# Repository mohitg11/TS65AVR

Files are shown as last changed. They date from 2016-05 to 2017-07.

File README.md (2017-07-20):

# TS65 - AVR Based
The Split 65% Keyboard - AVR Based

This is a custom 65% style keyboard that is split in the middle to provide a more ergonomic option whilst not being drastically different from the standard stagger used on keyboards

#Features
- Open Source Design
- Fully Programmable Keys
- Split design for better ergonomics, while maintaining the currently "standard" keyboard layput
- PCBs and case designed so that the two sides can be aligned perfectly like a 65%, for others using the board, cleaner desk while not at it, etc.
- Multiple layers
- Alps/Cherry (PCB/Plate) switch support
- PCB mount stabs supported
- Backlight LED on top to maintain compatibility with the few backlit keysets out there
- 3 Indicator + CapsLock LED
- 18 SMD RGB LEDs on the bottom of the PCB for under/side glow
- SMD (SOD-123) diodes
- Individual resistors for the LEDs not required as it uses a dedicated LED driver
- Using large (0805) capacitors and resistors so it is easier to hand-solder

#Optional Features Supported
- Possibility to add a buzzer
- Possibility to add a PS/2 trackpoint to either halves.
- Possibility to add a rotary dial for changing volume, LED brightness, etc.

#Layout options
- Split backspace
- Split left shift
- ISO support
- Off-center capslock
- 2.75 and 1.75 right shift
- Lots of options for bottom row

In the below image you can see the different options available, the top four rows represent the four rows of th keyboard and the options for the final keyboard row is represented by the remaining rows in the image.
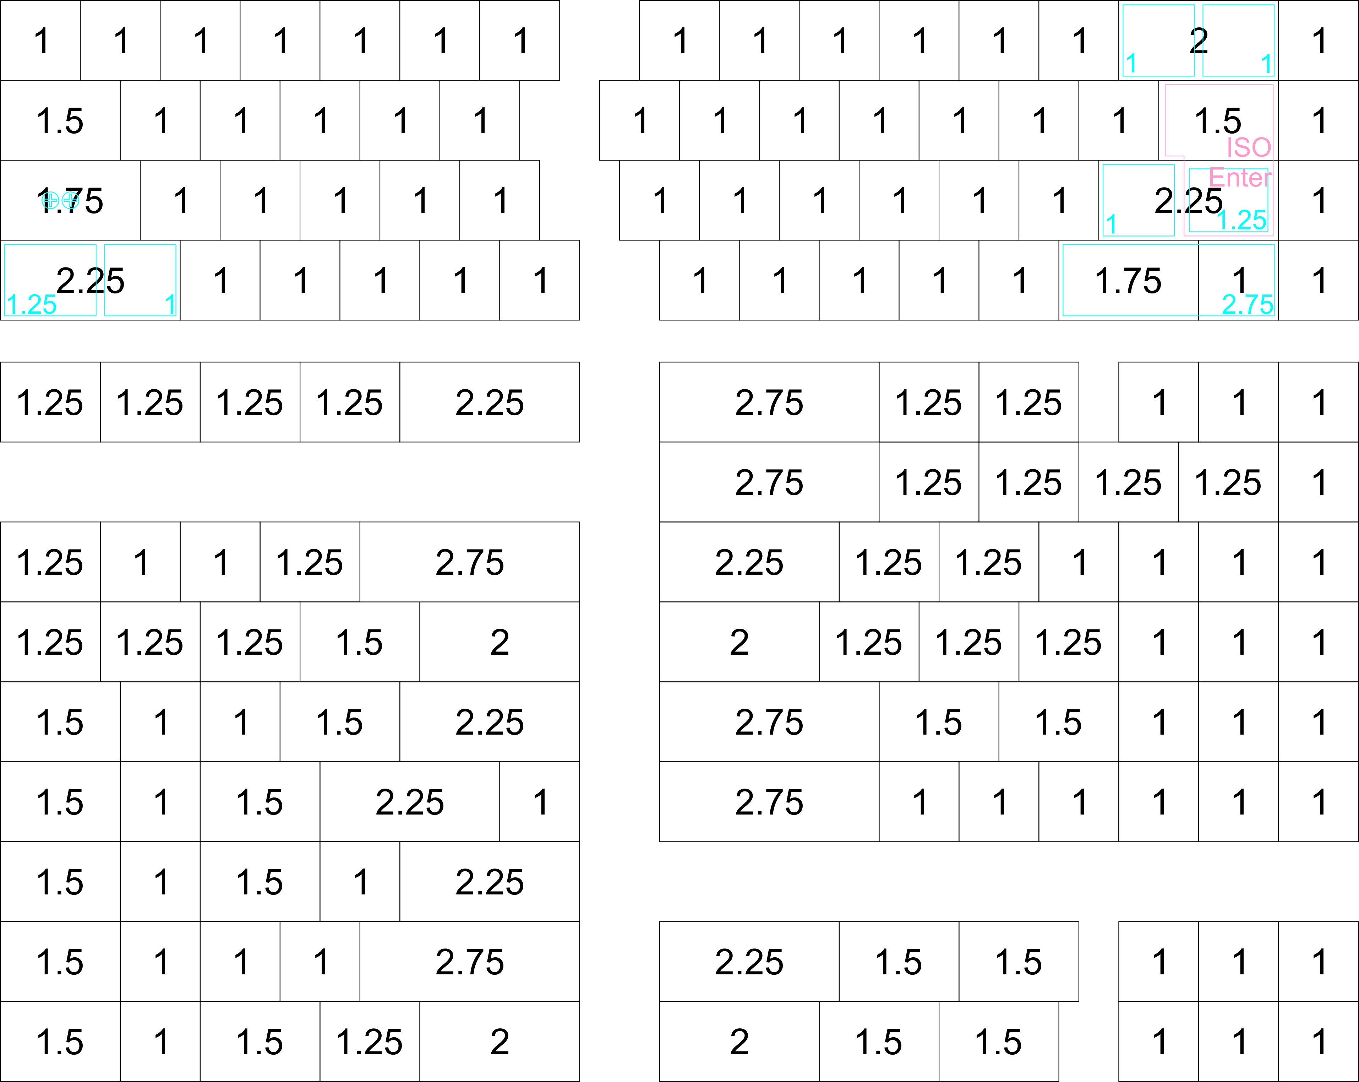
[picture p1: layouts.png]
Layout Options


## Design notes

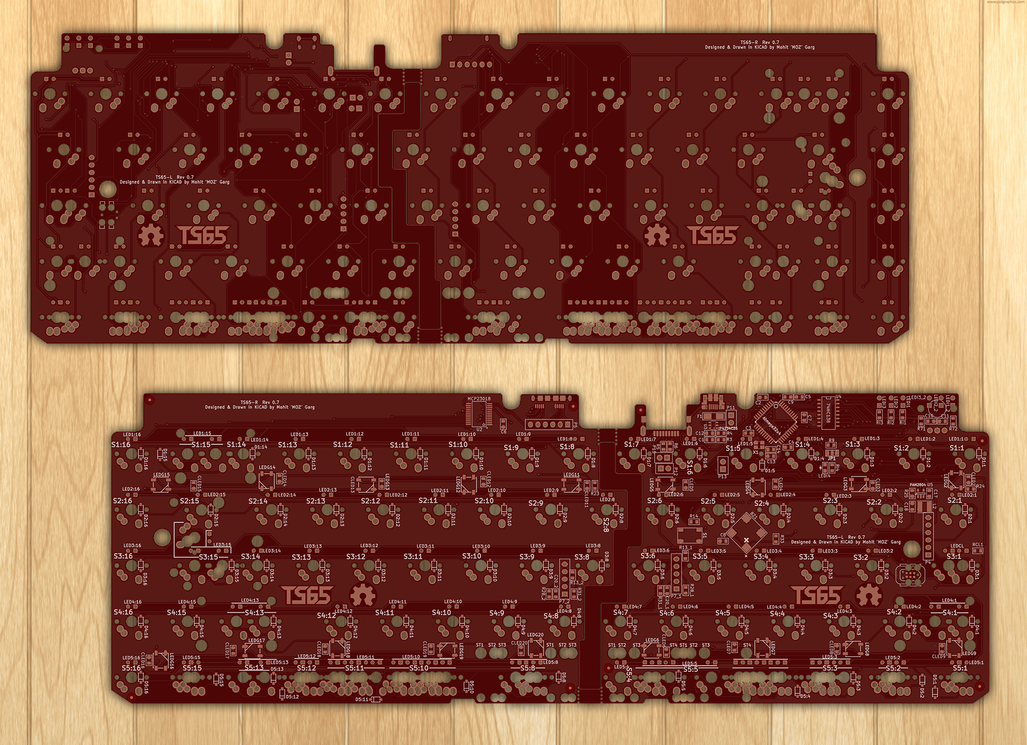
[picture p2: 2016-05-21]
PCB.png

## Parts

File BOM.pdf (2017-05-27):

# | Reference | Value | Qty | Description | Product | Vendor

1 | C1, C2 | 1uF | 2 | CAP CER 1UF 10V 10% X7R 0805 | CC0805KKX7R6BB105 | Yageo
2 | C12, C17, C18 | 10uF | 3 | CAP CER 10UF 6.3V X5R 0805 | CC0805KKX5R5BB106 | Yageo
3 | C13, C14 | 8pF | 2 | CAP CER 8PF 50V NP0 0805 | CC0805DRNPO9BN8R0 | Yageo
4 | CLED1 ‐ CLED20, C3‐C7, C9 | 0.1 uF | 24 | CAP CER 0.1UF 16V X7R 0805 | CL21B104KOANNNC | Yageo
5 | D1:1 ‐ D5:16 | DIODE | 73 | 1N4148 SOD123 DIODE | 1N4148W‐FDICT‐ND | Diodes Inc
6 | F1 | PTC FUSE | 1 | PTC RESTTBLE 1.0A 6V CHIP 1206 | 0ZCJ0100FF2E | Bel Fuse Inc
7 | L2 | 4.7uH | 1 | FIXED IND 4.7UH 1.9A 84 MOHM SMD | SRN4018‐4R7M | Bourns Inc
8 | LED1:1 | LED | 76 | 2x3x4mm 1.8mm 3mm flangeless LED
9 | LEDG2 - LEDG9, LEDG11 - LEDG20 WS2812B | 18 | LED RGB WS2812B W/DVR 4SMD 10PK | WS2812B | WorldSemi
10 | LEDI4 | LED | 1 | 0805 SMD LED
11 | P1 | USB_CONN | 1 | USB Micro B Female | 10103594‐0001LF | Amphenol
12 | P2 | USB3 | 1 | USB 3.0 A Female | AU-Y1006-3 | Assmann WSW Components
13 | P3 | USB3_MICRO | 1 | USB 3.0 Micro B Female | GSB343K33HR | Amphenol
14 | R23. R24 | 330 | 2 | RES SMD 330 OHM 1% 1/8W 0805 | RC0805FR‐07330RL | Yageo
15 | R25 | RLED | 1 | Resistor to set LED current select 0.1/I | RL0805FR‐7W0R5L | Yageo
16 | R3, R4 | 22 | 2 | RES SMD 22 OHM 5% 1/8W 0805 | RC0805FR‐0722RL | Yageo
17 | R9 | 10k | 1 | RES SMD 10K OHM 1% 1/8W 0805 | RC0805FR‐0710KL | Yageo
18 | R5, R6 | 2.2k | 2 | RES SMD 2.2K OHM 1% 1/8W 0805 | RC0805FR‐072K2L | Yageo
19 | R14 | 100k | 2 | RES SMD 100K OHM 1% 1/8W 0805 | RC0805FR‐07100KL | Yageo
20 | RCL1, RI1‐RI4 | 470 | 5 | 0805 Resistor for LED | RC0805FR‐07470KL | Yageo
21 | S1 | TAC_SWITCH | 1 | SWITCH TACTILE SPST‐NO 0.02A 15V | PTS525SM15SMTR2 LFS | C&K Components
22 | S1:1 ‐ S5:16 | SW | 73 | MX Alps or compatible switch
23 | U1 | Atmega32u4 | 1 | IC MCU 8BIT 32KB FLASH 44TQFP | ATMEGA32U4‐AU | Atmel
24 | U2 | MCP23018 | 1 | IC I/O EXPANDER I2C 16B 24SSOP | MCP23018‐E/SS | Microchip
25 | U3 | IP4234CZ6 | 1 | TVS DIODE 5.5VWM 6TSOP | IP4234CZ6 | NXP
26 | U4 | 74HC138 | 1 | IC DECODER/DEMUX 3‐8 LINE 16SOIC | 74HC138D | NXP
27 | U5 | PAM2804 | 1 | LED Driver IC 1 Output DC DC Buck 1A | PAM2804AAB010 | Diodes Inc
28 | X1 | CRYSTAL | 1 | Crystal 16.0000MHz 15ppm 8pF 50 Ohm | NX3225SA‐16.000MHZ‐STD‐CSR‐1 | NDK
# | Buzzer (Optional)

1 | BZ1 | BUZZER | 1 | BUZZER MAGNETIC 3.6V 8.5MM SMD | SMT‐0931‐S‐R | PUI Audio Inc
2 | C8 | 0.1uF | 1 | CAP CER 0.1UF 16V X7R 0805 | CL21B104KOANNNC | Yageo
3 | R33 | 100 | 1 | RES SMD 100 OHM 1% 1/8W 0805 | RC0805FR‐07100RL | Yageo
# | Trackpoint (Optional)

1 | C20 | 2.2uF | 1 | CAP CER 2.2UF 10V X7R 0805 | CC0805KKX7R6BB225 | Yageo
2 | R13 | 100k | 1 | RES SMD 100K OHM 1% 1/8W 0805 | RC0805FR‐07100KL | Yageo
3 | R28, R31 | 4.7k | 2 | RES SMD 4.7K OHM 1% 1/8W 0805 | RC0805FR‐074K7L | Yageo
# | Rotary Encoder (Optional)

1 | C10, C11 | 1uF | 2 | CAP CER 1UF 10V 10% X7R 0805 | CC0805KKX7R6BB105 | Yageo
2 | R71, R72 | 10k | 2 | RES SMD 10K OHM 1% 1/8W 0805 | RC0805FR‐0710KL | Yageo
3 | S2 | ENCODER | 1 | ENCODER ROTARY | PEC12R‐4017F‐N0024 | Bourns Inc

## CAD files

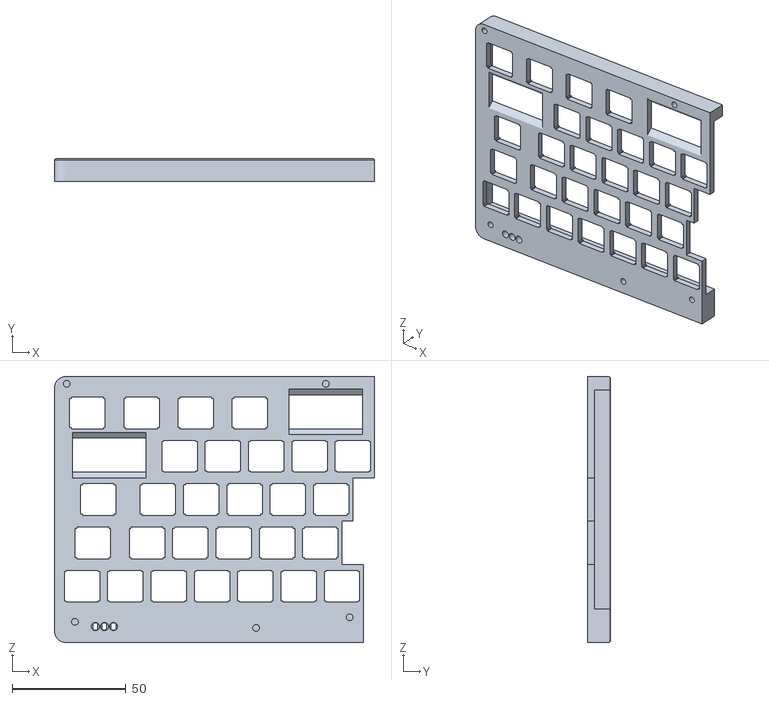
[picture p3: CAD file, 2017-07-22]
Case/3d Printed/Plate-Left.stl
140.7 x 10.0 x 117.0

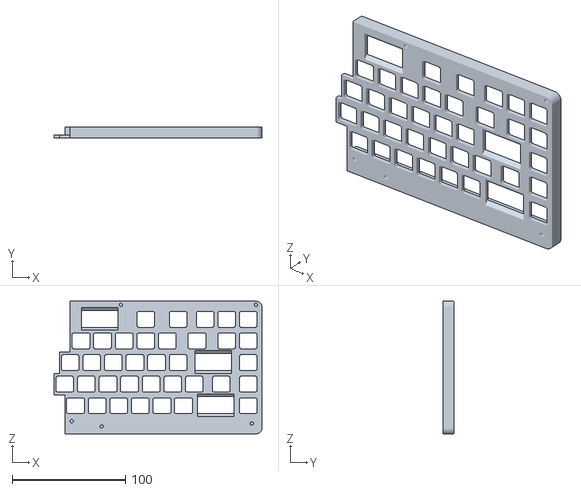
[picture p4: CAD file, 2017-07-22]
Case/3d Printed/Plate-Right.stl
183.6 x 10.0 x 117.0

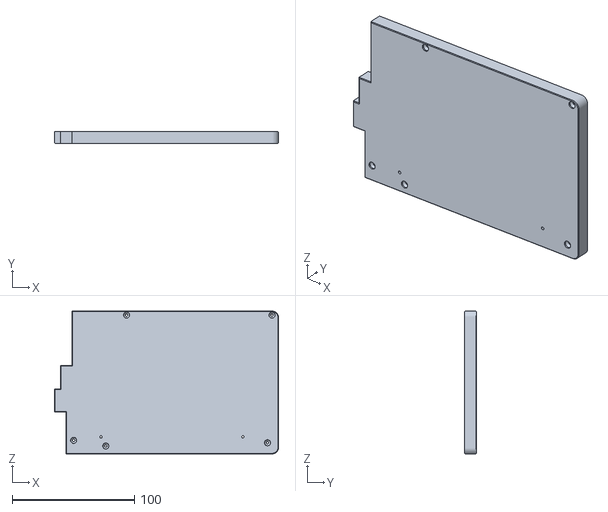
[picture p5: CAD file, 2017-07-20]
Case/3d Printed/Bottom-Right.stl
183.6 x 10.0 x 117.0

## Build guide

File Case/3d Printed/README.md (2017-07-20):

# 3d printed case

A 3d printed case for the TS65 keyboard by GH/MajorKoos.  
This model is designed for printing on a FDM printer without the need for supports.

#McMaster-Carr parts #:
- 94180A307    Heat-Set Inserts for Plastics M2 x 0.4 mm Thread Size, 2.9 mm 
- 91294A009    Black-Oxide Alloy Steel Hex Drive Flat Head Screw M2 x 0.4 mm Thread, 12 mm Long

#Reference
https://geekhack.org/index.php?topic=79161.msg2462175#msg2462175

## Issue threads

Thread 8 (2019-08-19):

ISO Layout for Plate files

sachin3767, 2019-08-19:
Hi, I've been following the TS65 on GH which led me here. I hope this git is still being updated.

Would it be possible to have an ISO layout for the plate files? Mostly to provide others with some options on layouts. I much prefer the fixed layout as you have for ANSI, but separate files for other layouts would be handy.

[KLE example layout](http://www.keyboard-layout-editor.com/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"%0A'&=%60%0A~&_x:1.25&c=%235b6e7f&a:7%3B&=PGUP%3B&@_w:1.25%3B&=SHIFT&_c=%23dcd9d4&a:5%3B&=%5C%0A%7C&_a:7%3B&=Z&=X&=C&=V&=B&_x:0.75%3B&=N&=M&=,&=.&=%2F%2F&_c=%235b6e7f&w:1.75%3B&=SHIFT&_c=%23ffb734%3B&=UP&_c=%235b6e7f%3B&=PGDN%3B&@_w:1.25%3B&=CTRL&_w:1.25%3B&=WIN&_c=%23ffb734&w:1.25%3B&=FN&_c=%235b6e7f&w:1.25%3B&=ALT&_c=%23ffb734&w:2.25%3B&=&_x:0.75&c=%235b6e7f&w:2.75%3B&=&=ALT&_c=%23ffb734%3B&=FN&_c=%235b6e7f%3B&=CTRL&_c=%23ffb734%3B&=LEFT&=DN&=RIGHT)

Thank you

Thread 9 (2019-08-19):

BOM does not include trackpoint product code

sachin3767, 2019-08-19:
As the title suggests, I cannot see a trackpoint product code. Where would I find a compatible trackpoint for this PCB?

coddingtonbear, 2019-12-01:
It's unlikely you're going to be able to find a useful product code for such a thing.   Essentially -- you just need to find a trackpoint with PS/2 support; you can find a brief overview of some known-compatible trackpoints here: https://deskthority.net/wiki/TrackPoint_Hardware.  What _I_ did in my design was harvest a trackpoint from a Lenovo R61 keyboard.

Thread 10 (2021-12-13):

0805 Resistor for LED is 470 or 470k?

NewTX, 2021-12-13:
Hi, I don't know much about hardware, so this makes me confuse.
In BOM-TS65.xlsx, No20 is 0805 resistor for LED. It's value is 470, but the product code "RC0805FR‐07470KL" is for 470k.
So, which one should I use?'

Thank you.

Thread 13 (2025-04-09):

Suspected Fake Star Pumping and Dishonest Behavior 🚨

steinmetz-phillipi, 2025-04-09:
Hey there 👋,

First off, love seeing creative projects on GitHub, but I stumbled upon something strange here. It seems like your repo's GitHub stars grew suspiciously fast—like unrealistically fast, to the point it looks like someone might have paid for fake stars or used some shady star-boosting methods.

Why's this a problem? Well, GitHub is all about genuine collaboration and sharing cool stuff, right? Buying fake stars or artificially inflating popularity hurts trust in the community and makes it unfair for other hardworking developers.

Mistakes happen, so if this was intentional or accidental, it’d be cool to own up to it and fix the situation. Authentic growth is far better long-term—you win genuine respect rather than superficial attention.

Maybe consider taking some steps to reset fake data/influences here? And trust me, if your project has value (it totally seems to), it’ll get deserved recognition organically.

Keeping GitHub awesome for everyone starts with each of us!✌️

coddingtonbear, 2025-04-09:
@mohitg11  --  I think any of us following this repo know that this claim is absolutely absurd given the star count of this repo.  Please don't feel weird just closing these unceremoniously.

Closed 2025-04-09.

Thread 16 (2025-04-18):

Unusual Spike in GitHub Stars - Questionable Practices?

cburton6338-o, 2025-04-18:
Hi there, I know open-source contributions and community recognition can be exciting, but I couldn’t help but notice an unusually sharp rise in the number of this project’s stars recently. It feels a bit off, almost like there’s some "help" involved, maybe star-buying? 😅

If this was intentional (or a misunderstanding gone funny), I’d strongly encourage reflecting on the real purpose of open source. Manipulating metrics just dilutes trust in the community. It's way cooler to have fewer but genuine supporters than inflated vanity numbers. Quality over quantity!

So, how about doing the right thing—owning up, clarifying or reversing any unintended actions DIY style? 😄 Transparency rocks, and the open-source world can show enough support naturally if you're passionate and persistent.

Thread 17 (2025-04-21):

关于项目的异常 Star 增长的疑问

ciara5054-hey2, 2025-04-21:
嗨，作者！最近注意到这个项目的 GitHub Star 数量在短时间内出现了异常的增长，看上去不像是自然获得的社区支持呢。这样的“刷 Star”行为，真的对开源项目的发展好吗？

开源社区重视的是透明、真实的贡献和价值，而不是表面的人气数字。如果这些 Star 是通过购买或者类似的方式获得的，我建议你重视这个问题，承认错误，并公开道歉。

虚假的人气可能一时看起来风光，但从长远来看，对项目的信任和声誉伤害更大。开源是关于真诚和共同进步的，希望你也能够以实际行动为社区树立一个正面的榜样！加油，我们都在期待一个更真实、更有价值的项目成长！

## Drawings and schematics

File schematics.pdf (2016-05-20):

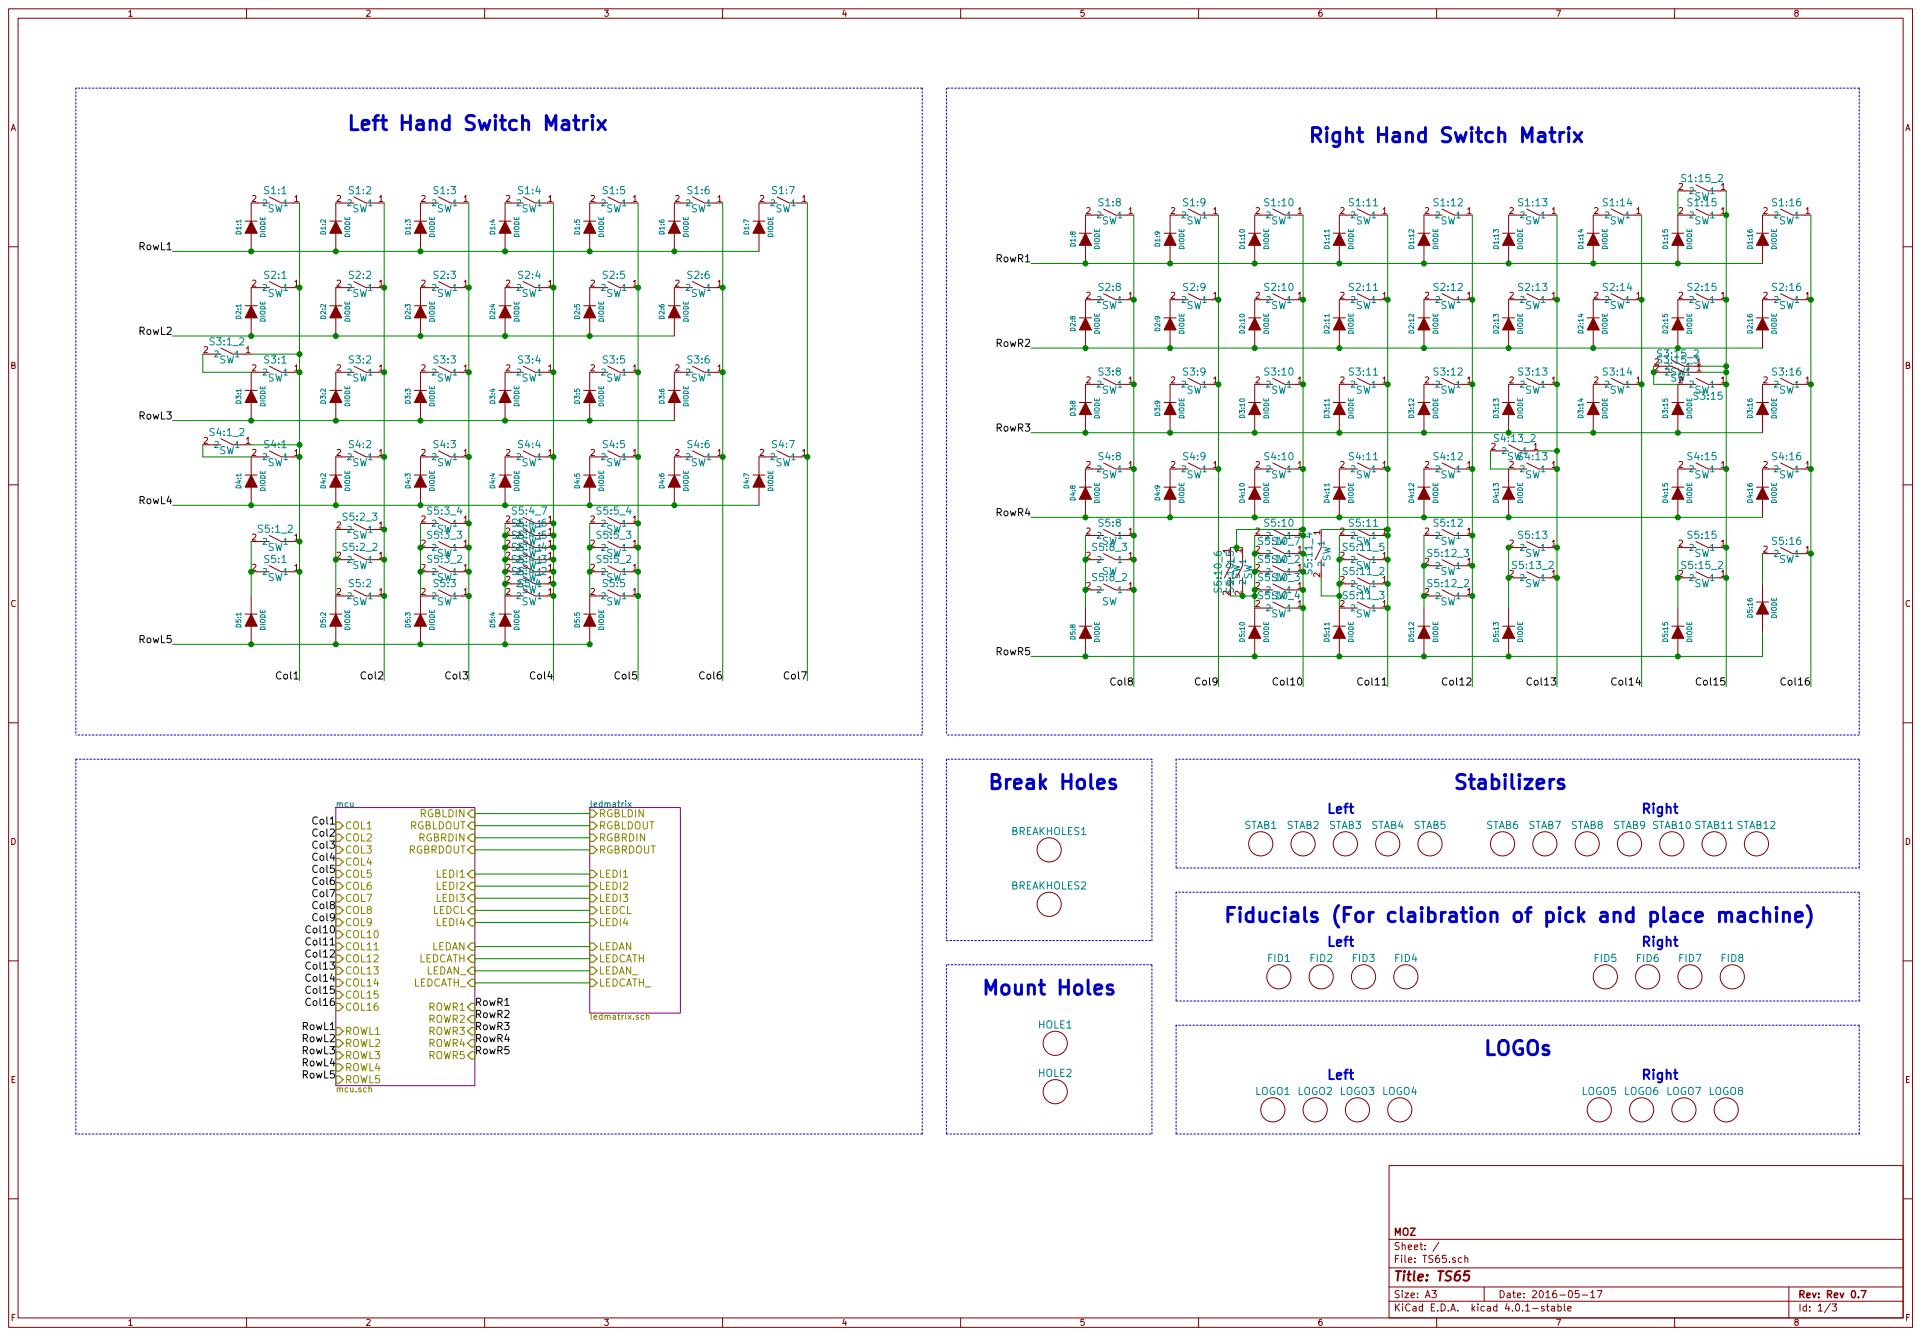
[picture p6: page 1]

File: TS65.sch Sheet: / MOZ BREAKHOLES2

Fiducials (For claibration of pick and place machine)

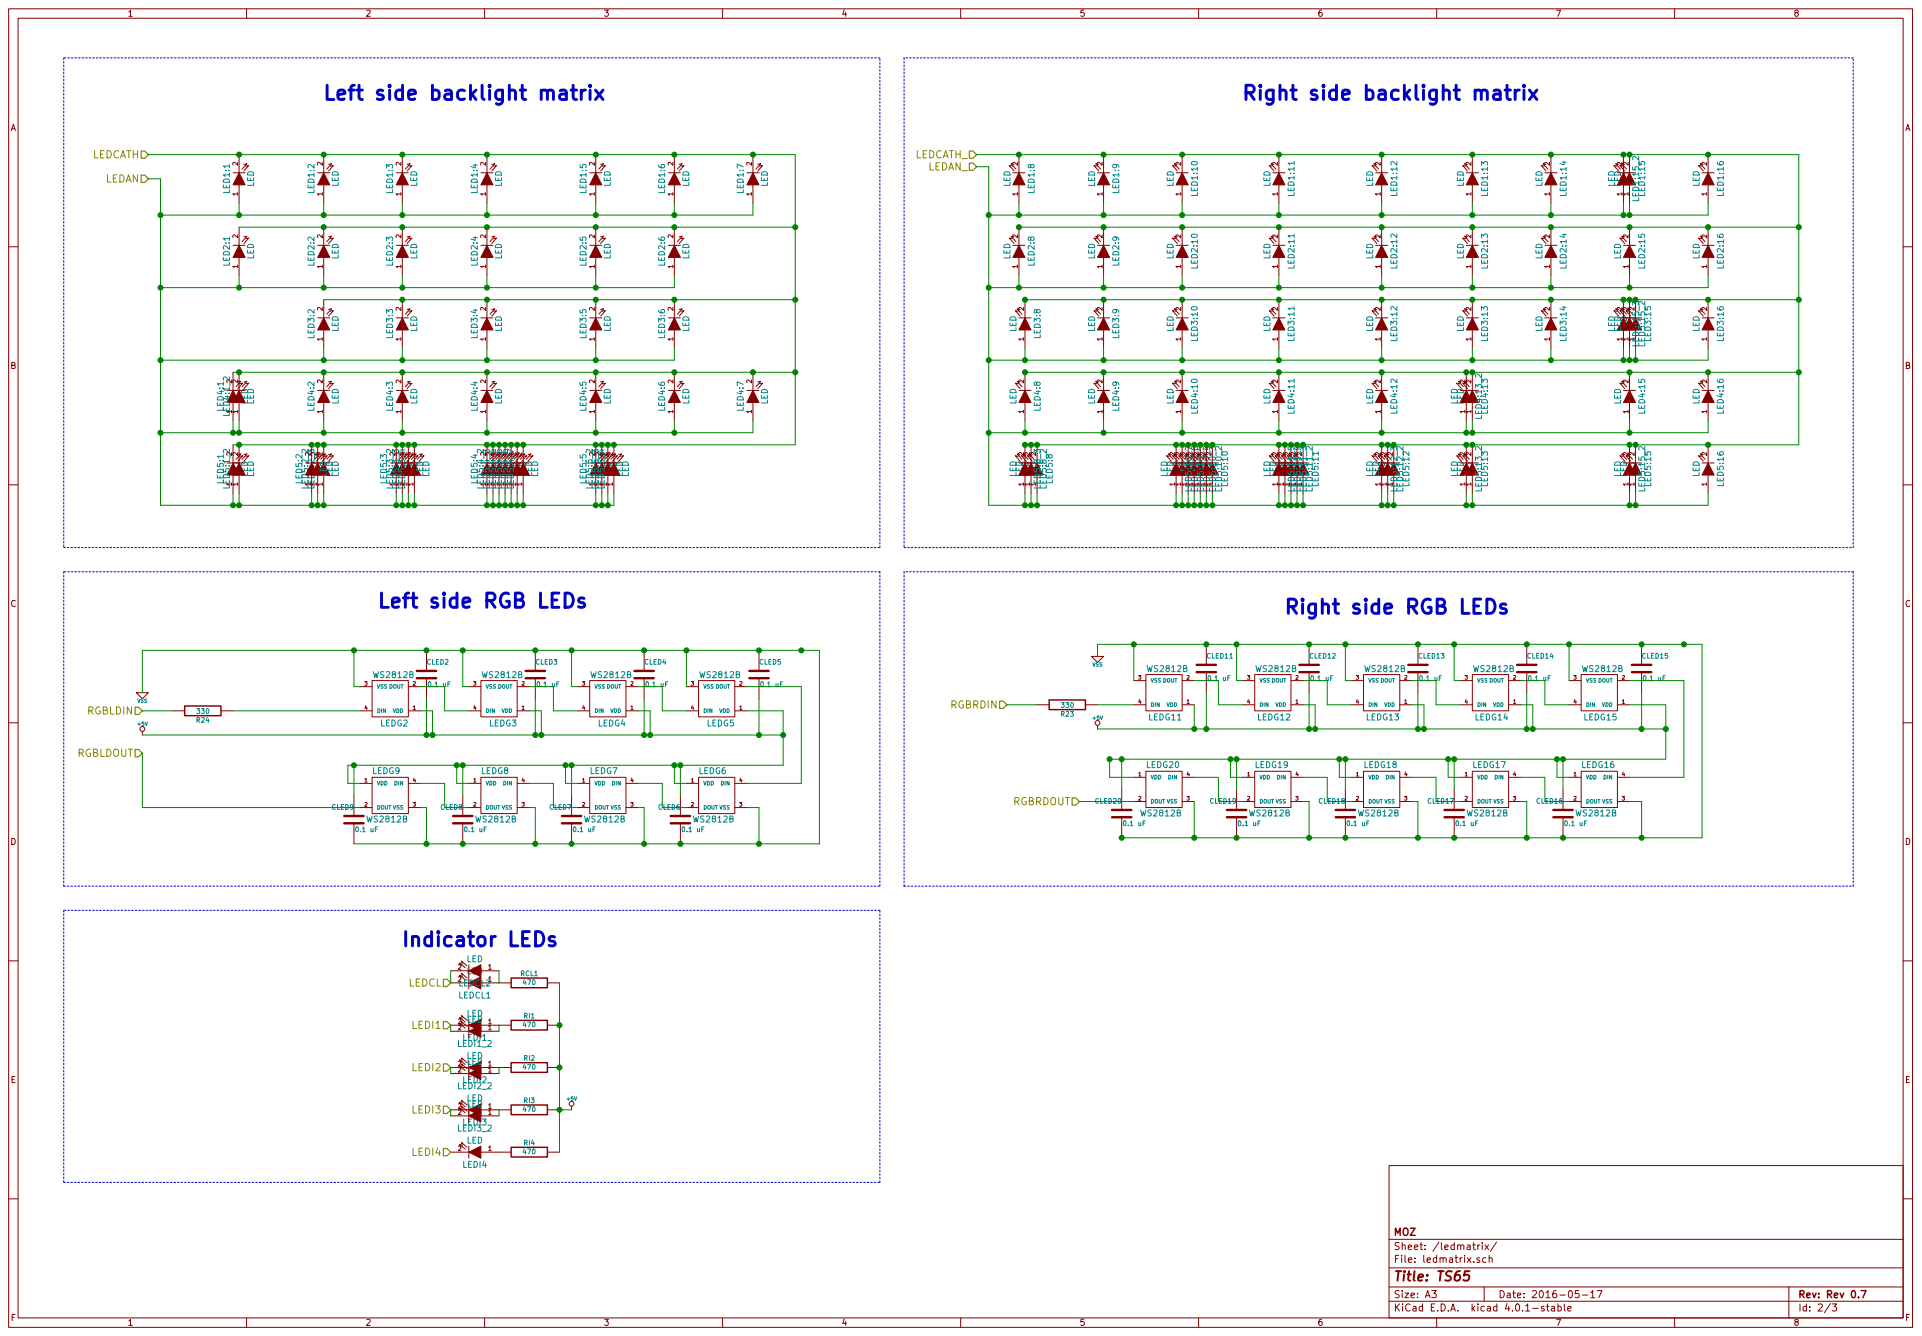
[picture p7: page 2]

0.1 uF | CLED12 0.1 uF | CLED13 0.1 uF | CLED14 0.1 uF | CLED15

0.1 uF | CLED3 0.1 uF | CLED4

File: ledmatrix.sch Sheet: /ledmatrix/ MOZ

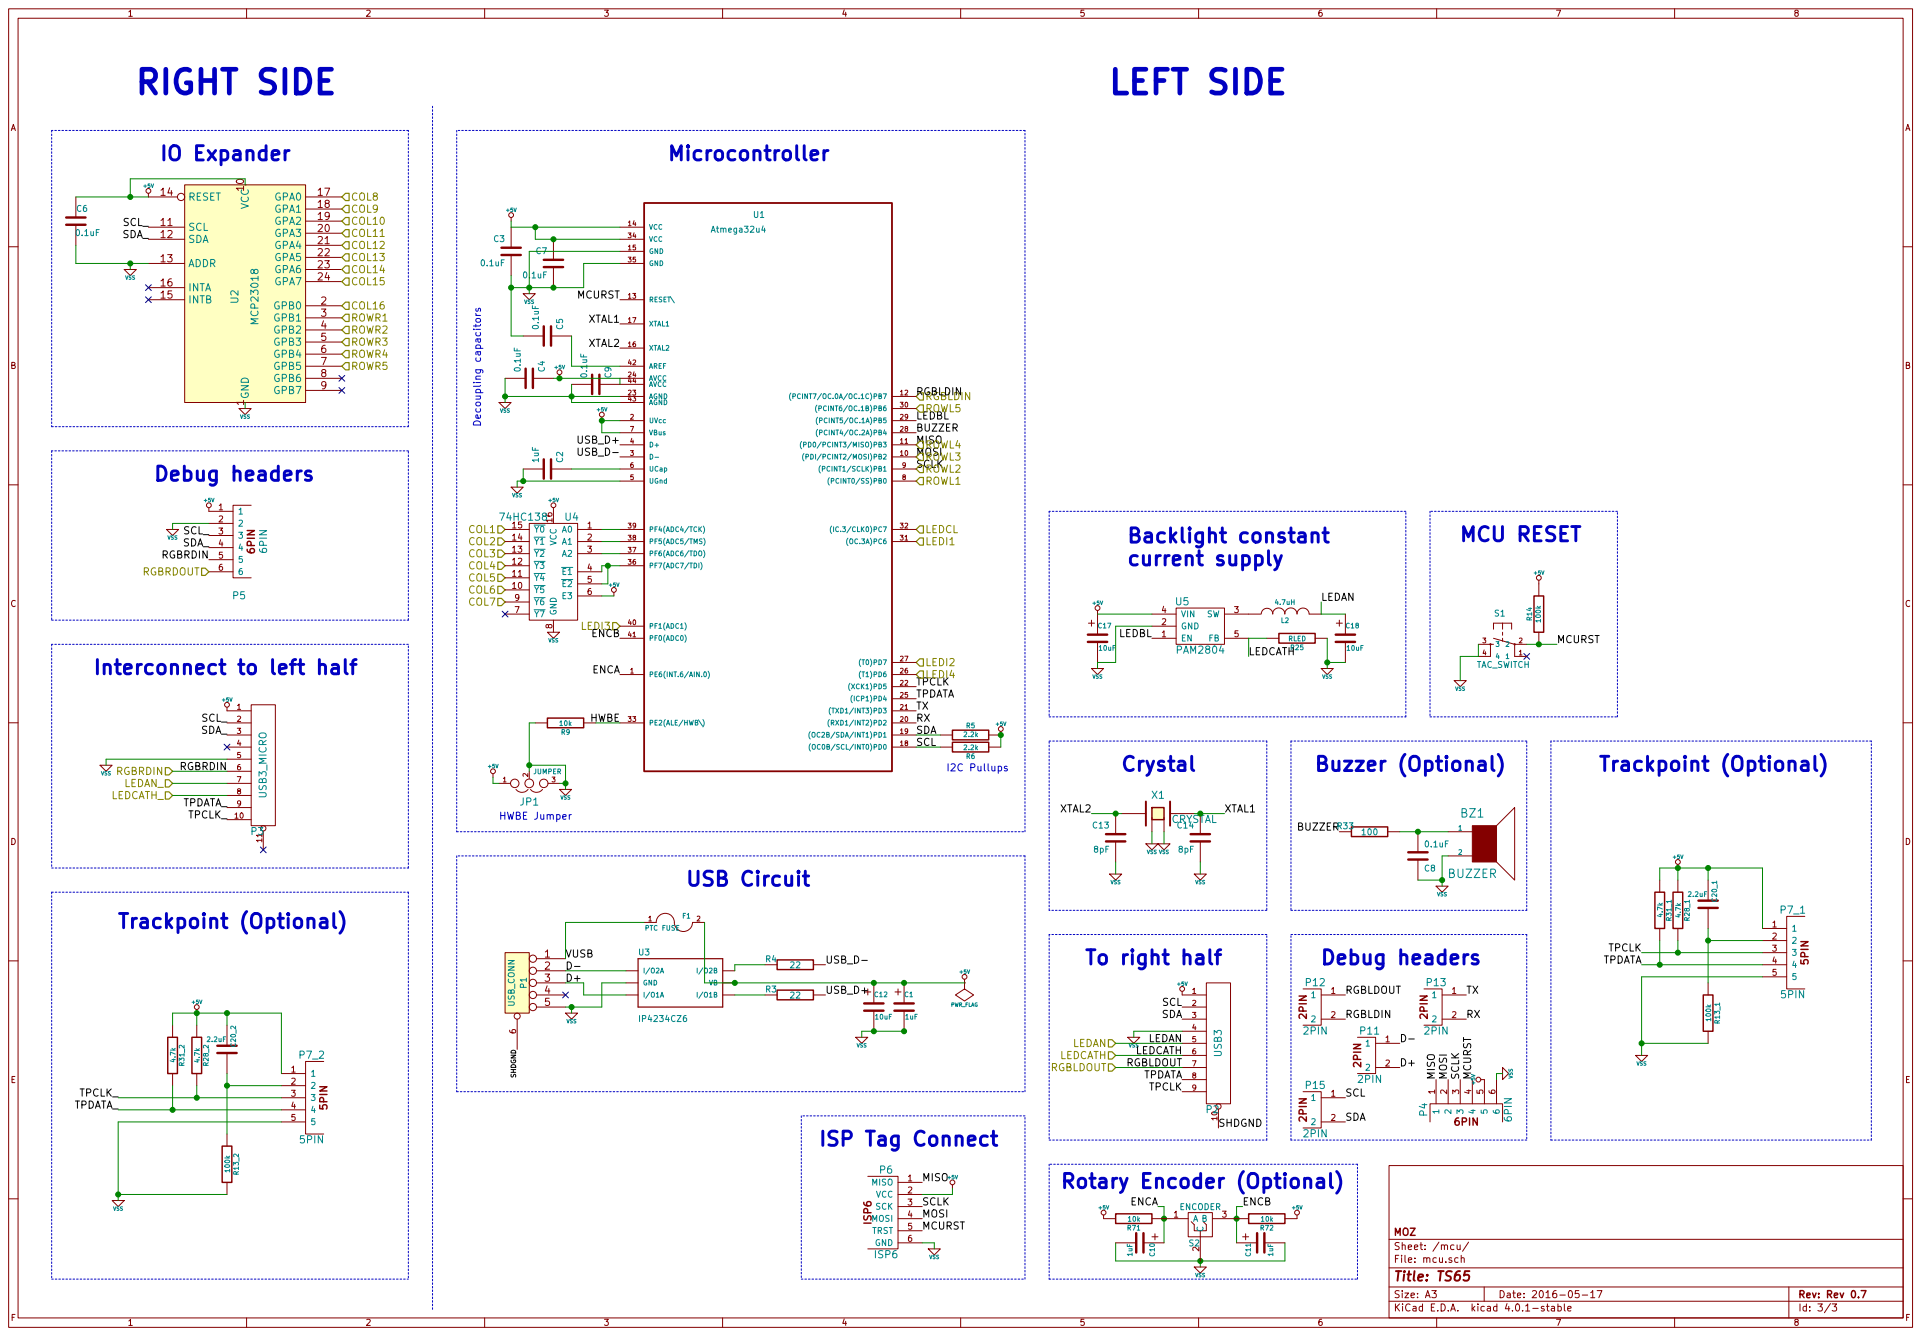
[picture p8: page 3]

Interconnect to left half

VSS BUZZER Buzzer (Optional)

File: mcu.sch Sheet: /mcu/ MOZ

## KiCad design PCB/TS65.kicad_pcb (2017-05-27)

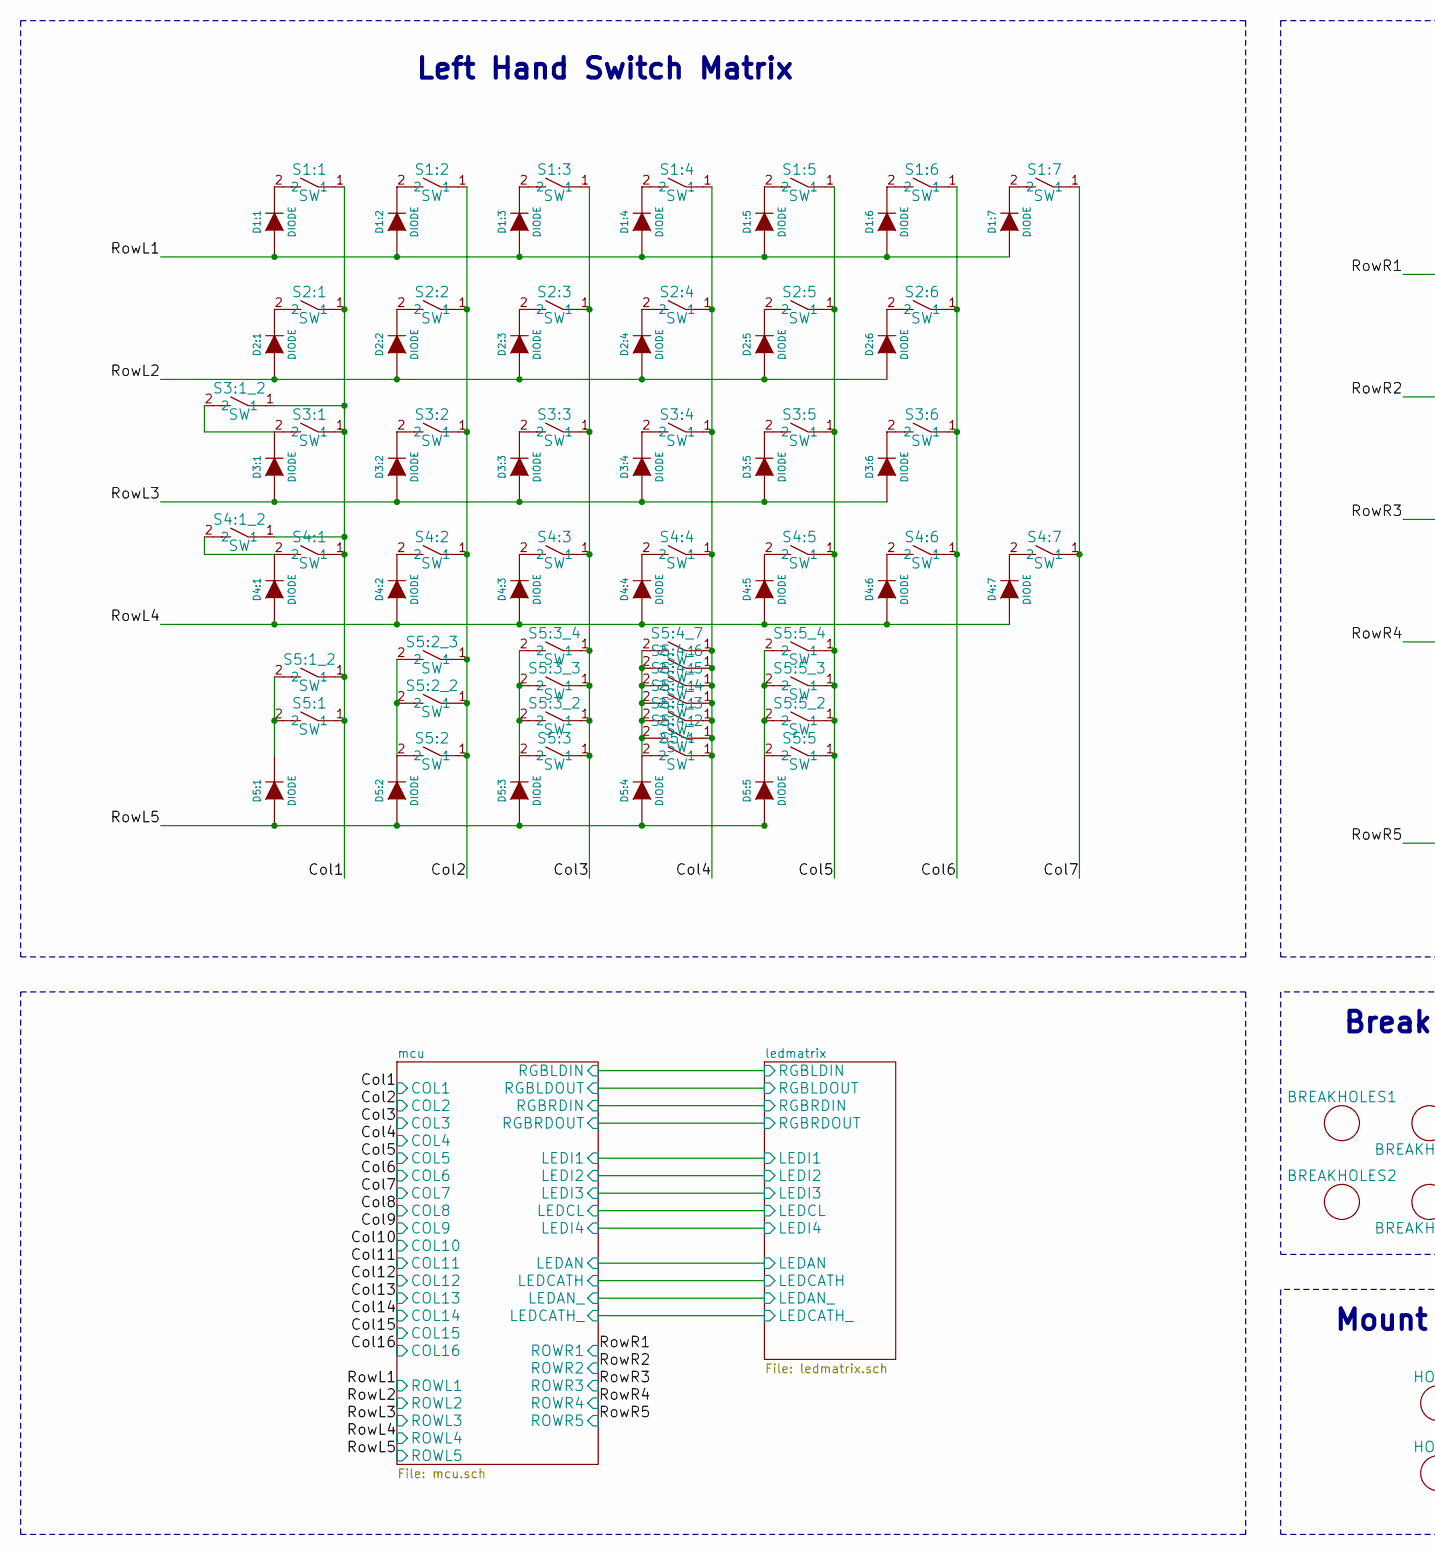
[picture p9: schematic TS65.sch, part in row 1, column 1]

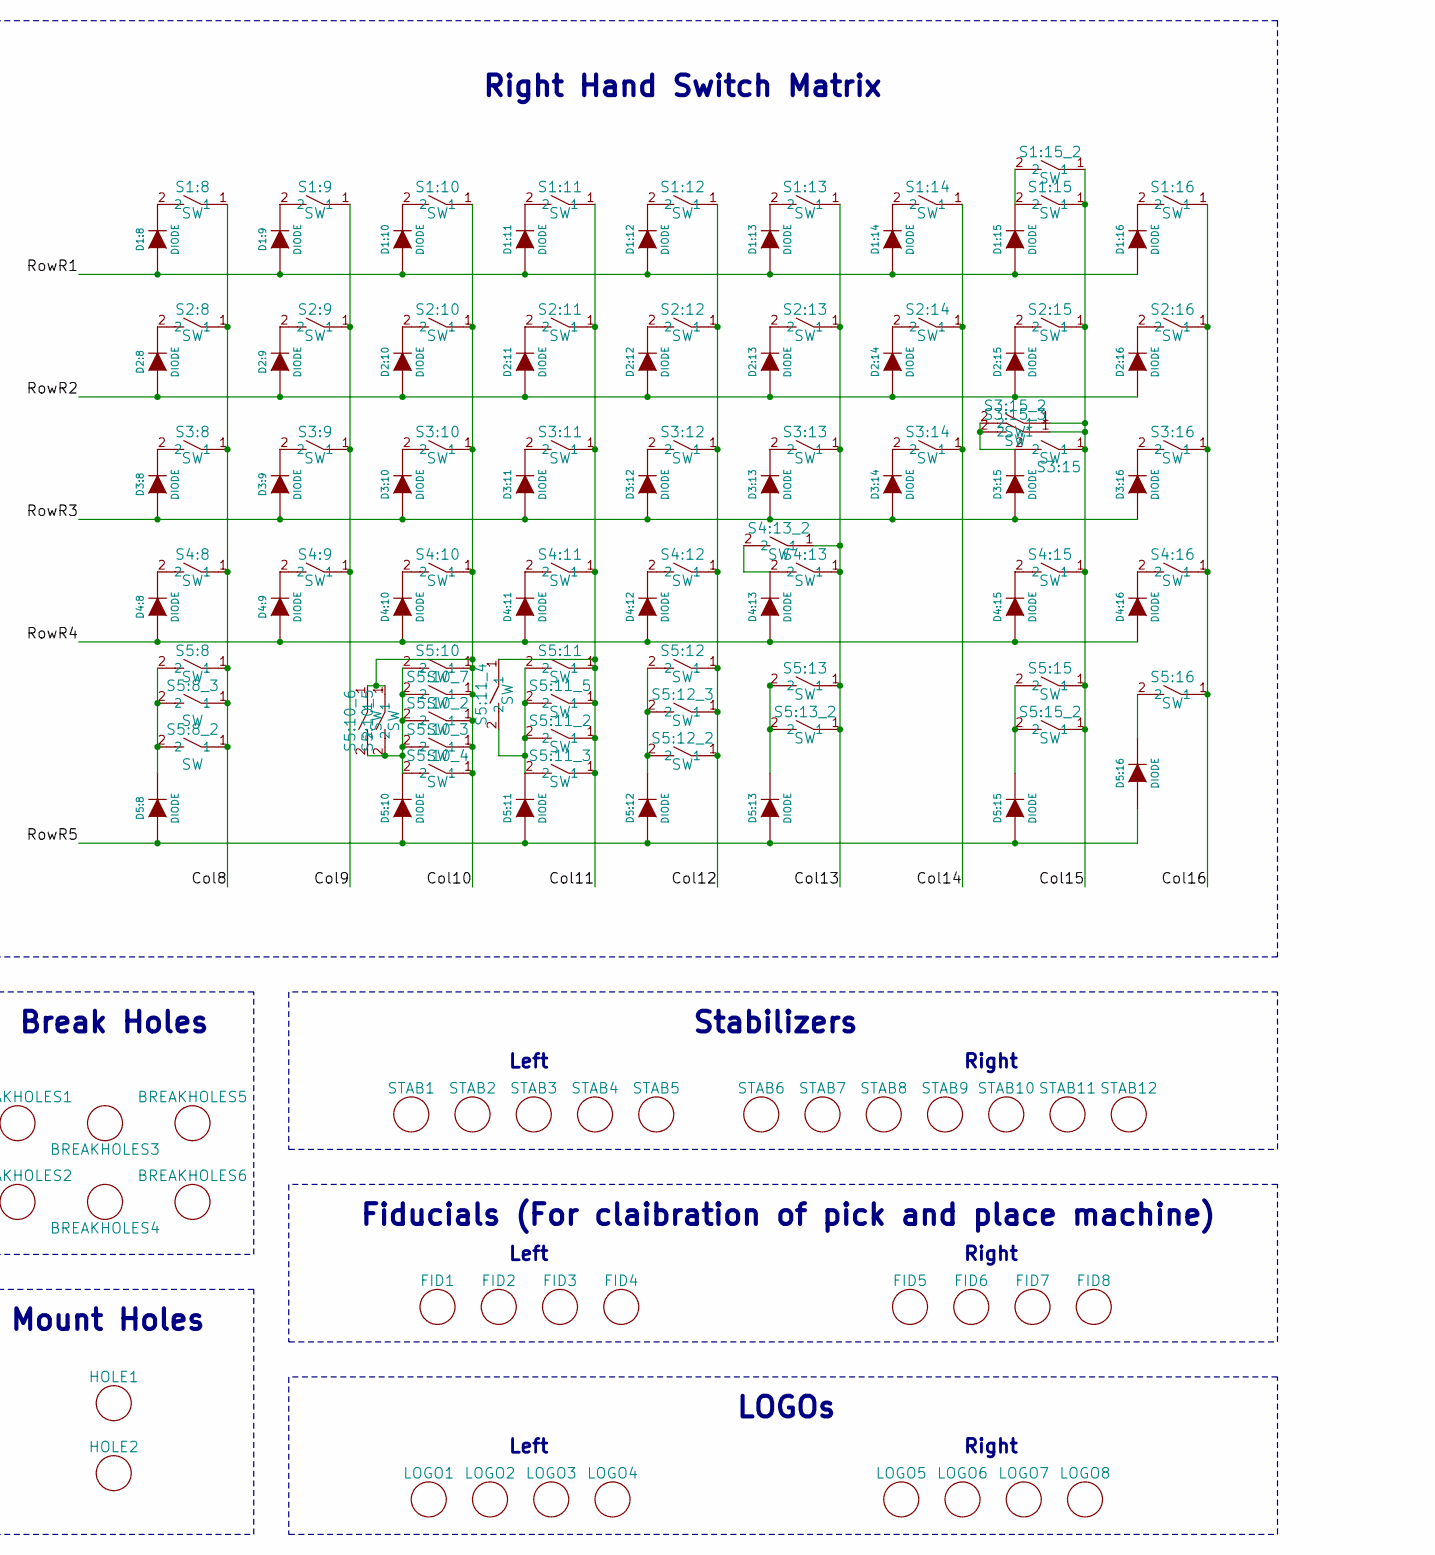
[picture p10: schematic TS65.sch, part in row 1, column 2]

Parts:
BREAKHOLES1, BREAKHOLES2, BREAKHOLES3, BREAKHOLES4, BREAKHOLES5, BREAKHOLES6: MISC; BreakHoles
D1:1, D1:2, D1:3, D1:4, D1:5, D1:6, D1:7, D1:8, D1:9, D1:10, D1:11, D1:12, D1:13, D1:14, D1:15, D1:16, D2:1, D2:2, D2:3, D2:4, D2:5, D2:6, D2:8, D2:9, D2:10, D2:11, D2:12, D2:13, D2:14, D2:15, D2:16, D3:1, D3:2, D3:3, D3:4, D3:5, D3:6, D3:8, D3:9, D3:10, D3:11, D3:12, D3:13, D3:14, D3:15, D3:16, D4:1, D4:2, D4:3, D4:4, D4:5, D4:6, D4:7, D4:8, D4:9, D4:10, D4:11, D4:12, D4:13, D4:15, D4:16, D5:1, D5:2, D5:3, D5:4, D5:5, D5:8, D5:10, D5:11, D5:12, D5:13, D5:15, D5:16: DIODE; SOD123-DIODE
FID1, FID2, FID3, FID4, FID5, FID6, FID7, FID8: MISC; FID
HOLE1, HOLE2: MISC; FID
LOGO1, LOGO2, LOGO5, LOGO6: MISC; TS65-LOGO
LOGO3, LOGO4, LOGO7, LOGO8: MISC; OSHW
S1:1, S1:2, S1:3, S1:4, S1:5, S1:6, S1:7, S1:8, S1:9, S1:10, S1:11, S1:12, S1:13, S1:14, S1:15, S1:15_2, S1:16, S2:1, S2:2, S2:3, S2:4, S2:5, S2:6, S2:8, S2:9, S2:10, S2:11, S2:12, S2:13, S2:14, S2:15, S2:16, S3:1, S3:1_2, S3:2, S3:3, S3:4, S3:5, S3:6, S3:8, S3:9, S3:10, S3:11, S3:12, S3:13, S3:14, S3:15, S3:15_2, S3:15_3, S3:16, S4:1, S4:1_2, S4:2, S4:3, S4:4, S4:5, S4:6, S4:7, S4:8, S4:9, S4:10, S4:11, S4:12, S4:13, S4:13_2, S4:15, S4:16, S5:1, S5:1_2, S5:2, S5:2_2, S5:2_3, S5:3, S5:3_2, S5:3_3, S5:3_4, S5:4, S5:4_2, S5:4_3, S5:4_4, S5:4_5, S5:4_6, S5:4_7, S5:5, S5:5_2, S5:5_3, S5:5_4, S5:8, S5:8_2, S5:8_3, S5:10, S5:10_2, S5:10_3, S5:10_4, S5:10_5, S5:10_6, S5:10_7, S5:11, S5:11_2, S5:11_3, S5:11_4, S5:11_5, S5:12, S5:12_2, S5:12_3, S5:13, S5:13_2, S5:15, S5:15_2, S5:16: SW; MXALPS2
STAB1, STAB2, STAB3, STAB4, STAB5, STAB6, STAB7, STAB8, STAB9, STAB10, STAB11, STAB12: MISC; MX_200

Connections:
/Col1: S1:1.1, S2:1.1, S3:1.1, S3:1_2.1, S4:1.1, S4:1_2.1, S5:1.1, S5:1_2.1; also elsewhere on the board
/Col2: S1:2.1, S2:2.1, S3:2.1, S4:2.1, S5:2.1, S5:2_2.1, S5:2_3.1; also elsewhere on the board
/Col3: S1:3.1, S2:3.1, S3:3.1, S4:3.1, S5:3.1, S5:3_2.1, S5:3_3.1, S5:3_4.1; also elsewhere on the board
/Col4: S1:4.1, S2:4.1, S3:4.1, S4:4.1, S5:4.1, S5:4_2.1, S5:4_3.1, S5:4_4.1, S5:4_5.1, S5:4_6.1, S5:4_7.1; also elsewhere on the board
/Col5: S1:5.1, S2:5.1, S3:5.1, S4:5.1, S5:5.1, S5:5_2.1, S5:5_3.1, S5:5_4.1; also elsewhere on the board
/Col6: S1:6.1, S2:6.1, S3:6.1, S4:6.1; also elsewhere on the board
/Col7: S1:7.1, S4:7.1; also elsewhere on the board
/Col8: S1:8.1, S2:8.1, S3:8.1, S4:8.1, S5:8.1, S5:8_2.1, S5:8_3.1; also elsewhere on the board
/Col9: S1:9.1, S2:9.1, S3:9.1, S4:9.1; also elsewhere on the board
/Col10: S1:10.1, S2:10.1, S3:10.1, S4:10.1, S5:10.1, S5:10_2.1, S5:10_3.1, S5:10_4.1, S5:10_5.1, S5:10_6.1, S5:10_7.1; also elsewhere on the board
/Col11: S1:11.1, S2:11.1, S3:11.1, S4:11.1, S5:11.1, S5:11_2.1, S5:11_3.1, S5:11_4.1, S5:11_5.1; also elsewhere on the board
/Col12: S1:12.1, S2:12.1, S3:12.1, S4:12.1, S5:12.1, S5:12_2.1, S5:12_3.1; also elsewhere on the board
/Col13: S1:13.1, S2:13.1, S3:13.1, S4:13.1, S4:13_2.1, S5:13.1, S5:13_2.1; also elsewhere on the board
/Col14: S1:14.1, S2:14.1, S3:14.1; also elsewhere on the board
/Col15: S1:15.1, S1:15_2.1, S2:15.1, S3:15.1, S3:15_2.1, S3:15_3.1, S4:15.1, S5:15.1, S5:15_2.1; also elsewhere on the board
/Col16: S1:16.1, S2:16.1, S3:16.1, S4:16.1, S5:16.1; also elsewhere on the board
/RowL1: D1:1.1 (A), D1:2.1 (A), D1:3.1 (A), D1:4.1 (A), D1:5.1 (A), D1:6.1 (A), D1:7.1 (A); also elsewhere on the board
/RowL2: D2:1.1 (A), D2:2.1 (A), D2:3.1 (A), D2:4.1 (A), D2:5.1 (A), D2:6.1 (A); also elsewhere on the board
/RowL3: D3:1.1 (A), D3:2.1 (A), D3:3.1 (A), D3:4.1 (A), D3:5.1 (A), D3:6.1 (A); also elsewhere on the board
/RowL4: D4:1.1 (A), D4:2.1 (A), D4:3.1 (A), D4:4.1 (A), D4:5.1 (A), D4:6.1 (A), D4:7.1 (A); also elsewhere on the board
/RowL5: D5:1.1 (A), D5:2.1 (A), D5:3.1 (A), D5:4.1 (A), D5:5.1 (A); also elsewhere on the board
/RowR1: D1:8.1 (A), D1:9.1 (A), D1:10.1 (A), D1:11.1 (A), D1:12.1 (A), D1:13.1 (A), D1:14.1 (A), D1:15.1 (A), D1:16.1 (A); also elsewhere on the board
/RowR2: D2:8.1 (A), D2:9.1 (A), D2:10.1 (A), D2:11.1 (A), D2:12.1 (A), D2:13.1 (A), D2:14.1 (A), D2:15.1 (A), D2:16.1 (A); also elsewhere on the board
/RowR3: D3:8.1 (A), D3:9.1 (A), D3:10.1 (A), D3:11.1 (A), D3:12.1 (A), D3:13.1 (A), D3:14.1 (A), D3:15.1 (A), D3:16.1 (A); also elsewhere on the board
/RowR4: D4:8.1 (A), D4:9.1 (A), D4:10.1 (A), D4:11.1 (A), D4:12.1 (A), D4:13.1 (A), D4:15.1 (A), D4:16.1 (A); also elsewhere on the board
/RowR5: D5:8.1 (A), D5:10.1 (A), D5:11.1 (A), D5:12.1 (A), D5:13.1 (A), D5:15.1 (A), D5:16.1 (A); also elsewhere on the board
unnamed: D1:1.2 (K), S1:1.2
unnamed: D1:2.2 (K), S1:2.2
unnamed: D1:3.2 (K), S1:3.2
unnamed: D1:4.2 (K), S1:4.2
unnamed: D1:5.2 (K), S1:5.2
unnamed: D1:6.2 (K), S1:6.2
unnamed: D1:7.2 (K), S1:7.2
unnamed: D1:8.2 (K), S1:8.2
unnamed: D1:9.2 (K), S1:9.2
unnamed: D1:10.2 (K), S1:10.2
unnamed: D1:11.2 (K), S1:11.2
unnamed: D1:12.2 (K), S1:12.2
unnamed: D1:13.2 (K), S1:13.2
unnamed: D1:14.2 (K), S1:14.2
unnamed: D1:15.2 (K), S1:15.2, S1:15_2.2
unnamed: D1:16.2 (K), S1:16.2
unnamed: D2:1.2 (K), S2:1.2
unnamed: D2:2.2 (K), S2:2.2
unnamed: D2:3.2 (K), S2:3.2
unnamed: D2:4.2 (K), S2:4.2
unnamed: D2:5.2 (K), S2:5.2
unnamed: D2:6.2 (K), S2:6.2
unnamed: D2:8.2 (K), S2:8.2
unnamed: D2:9.2 (K), S2:9.2
unnamed: D2:10.2 (K), S2:10.2
unnamed: D2:11.2 (K), S2:11.2
unnamed: D2:12.2 (K), S2:12.2
unnamed: D2:13.2 (K), S2:13.2
unnamed: D2:14.2 (K), S2:14.2
unnamed: D2:15.2 (K), S2:15.2
unnamed: D2:16.2 (K), S2:16.2
unnamed: D3:1.2 (K), S3:1.2, S3:1_2.2
unnamed: D3:2.2 (K), S3:2.2
unnamed: D3:3.2 (K), S3:3.2
unnamed: D3:4.2 (K), S3:4.2
unnamed: D3:5.2 (K), S3:5.2
unnamed: D3:6.2 (K), S3:6.2
unnamed: D3:8.2 (K), S3:8.2
unnamed: D3:9.2 (K), S3:9.2
unnamed: D3:10.2 (K), S3:10.2
unnamed: D3:11.2 (K), S3:11.2
unnamed: D3:12.2 (K), S3:12.2
unnamed: D3:13.2 (K), S3:13.2
unnamed: D3:14.2 (K), S3:14.2
unnamed: D3:15.2 (K), S3:15.2, S3:15_2.2, S3:15_3.2
unnamed: D3:16.2 (K), S3:16.2
unnamed: D4:1.2 (K), S4:1.2, S4:1_2.2
unnamed: D4:2.2 (K), S4:2.2
unnamed: D4:3.2 (K), S4:3.2
unnamed: D4:4.2 (K), S4:4.2
unnamed: D4:5.2 (K), S4:5.2
unnamed: D4:6.2 (K), S4:6.2
unnamed: D4:7.2 (K), S4:7.2
unnamed: D4:8.2 (K), S4:8.2
unnamed: D4:9.2 (K), S4:9.2
unnamed: D4:10.2 (K), S4:10.2
unnamed: D4:11.2 (K), S4:11.2
unnamed: D4:12.2 (K), S4:12.2
unnamed: D4:13.2 (K), S4:13.2, S4:13_2.2
unnamed: D4:15.2 (K), S4:15.2
unnamed: D4:16.2 (K), S4:16.2
unnamed: D5:1.2 (K), S5:1.2, S5:1_2.2
unnamed: D5:2.2 (K), S5:2.2, S5:2_2.2, S5:2_3.2
unnamed: D5:3.2 (K), S5:3.2, S5:3_2.2, S5:3_3.2, S5:3_4.2
unnamed: D5:4.2 (K), S5:4.2, S5:4_2.2, S5:4_3.2, S5:4_4.2, S5:4_5.2, S5:4_6.2, S5:4_7.2
unnamed: D5:5.2 (K), S5:5.2, S5:5_2.2, S5:5_3.2, S5:5_4.2
unnamed: D5:8.2 (K), S5:8.2, S5:8_2.2, S5:8_3.2
unnamed: D5:10.2 (K), S5:10.2, S5:10_2.2, S5:10_3.2, S5:10_4.2, S5:10_5.2, S5:10_6.2, S5:10_7.2
unnamed: D5:11.2 (K), S5:11.2, S5:11_2.2, S5:11_3.2, S5:11_4.2, S5:11_5.2
unnamed: D5:12.2 (K), S5:12.2, S5:12_2.2, S5:12_3.2
unnamed: D5:13.2 (K), S5:13.2, S5:13_2.2
unnamed: D5:15.2 (K), S5:15.2, S5:15_2.2
unnamed: D5:16.2 (K), S5:16.2

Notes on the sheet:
Left Hand Switch Matrix
Right Hand Switch Matrix
Right
Left
Stabilizers
Fiducials (For claibration of pick and place machine)
LOGOs
Break Holes
Mount Holes

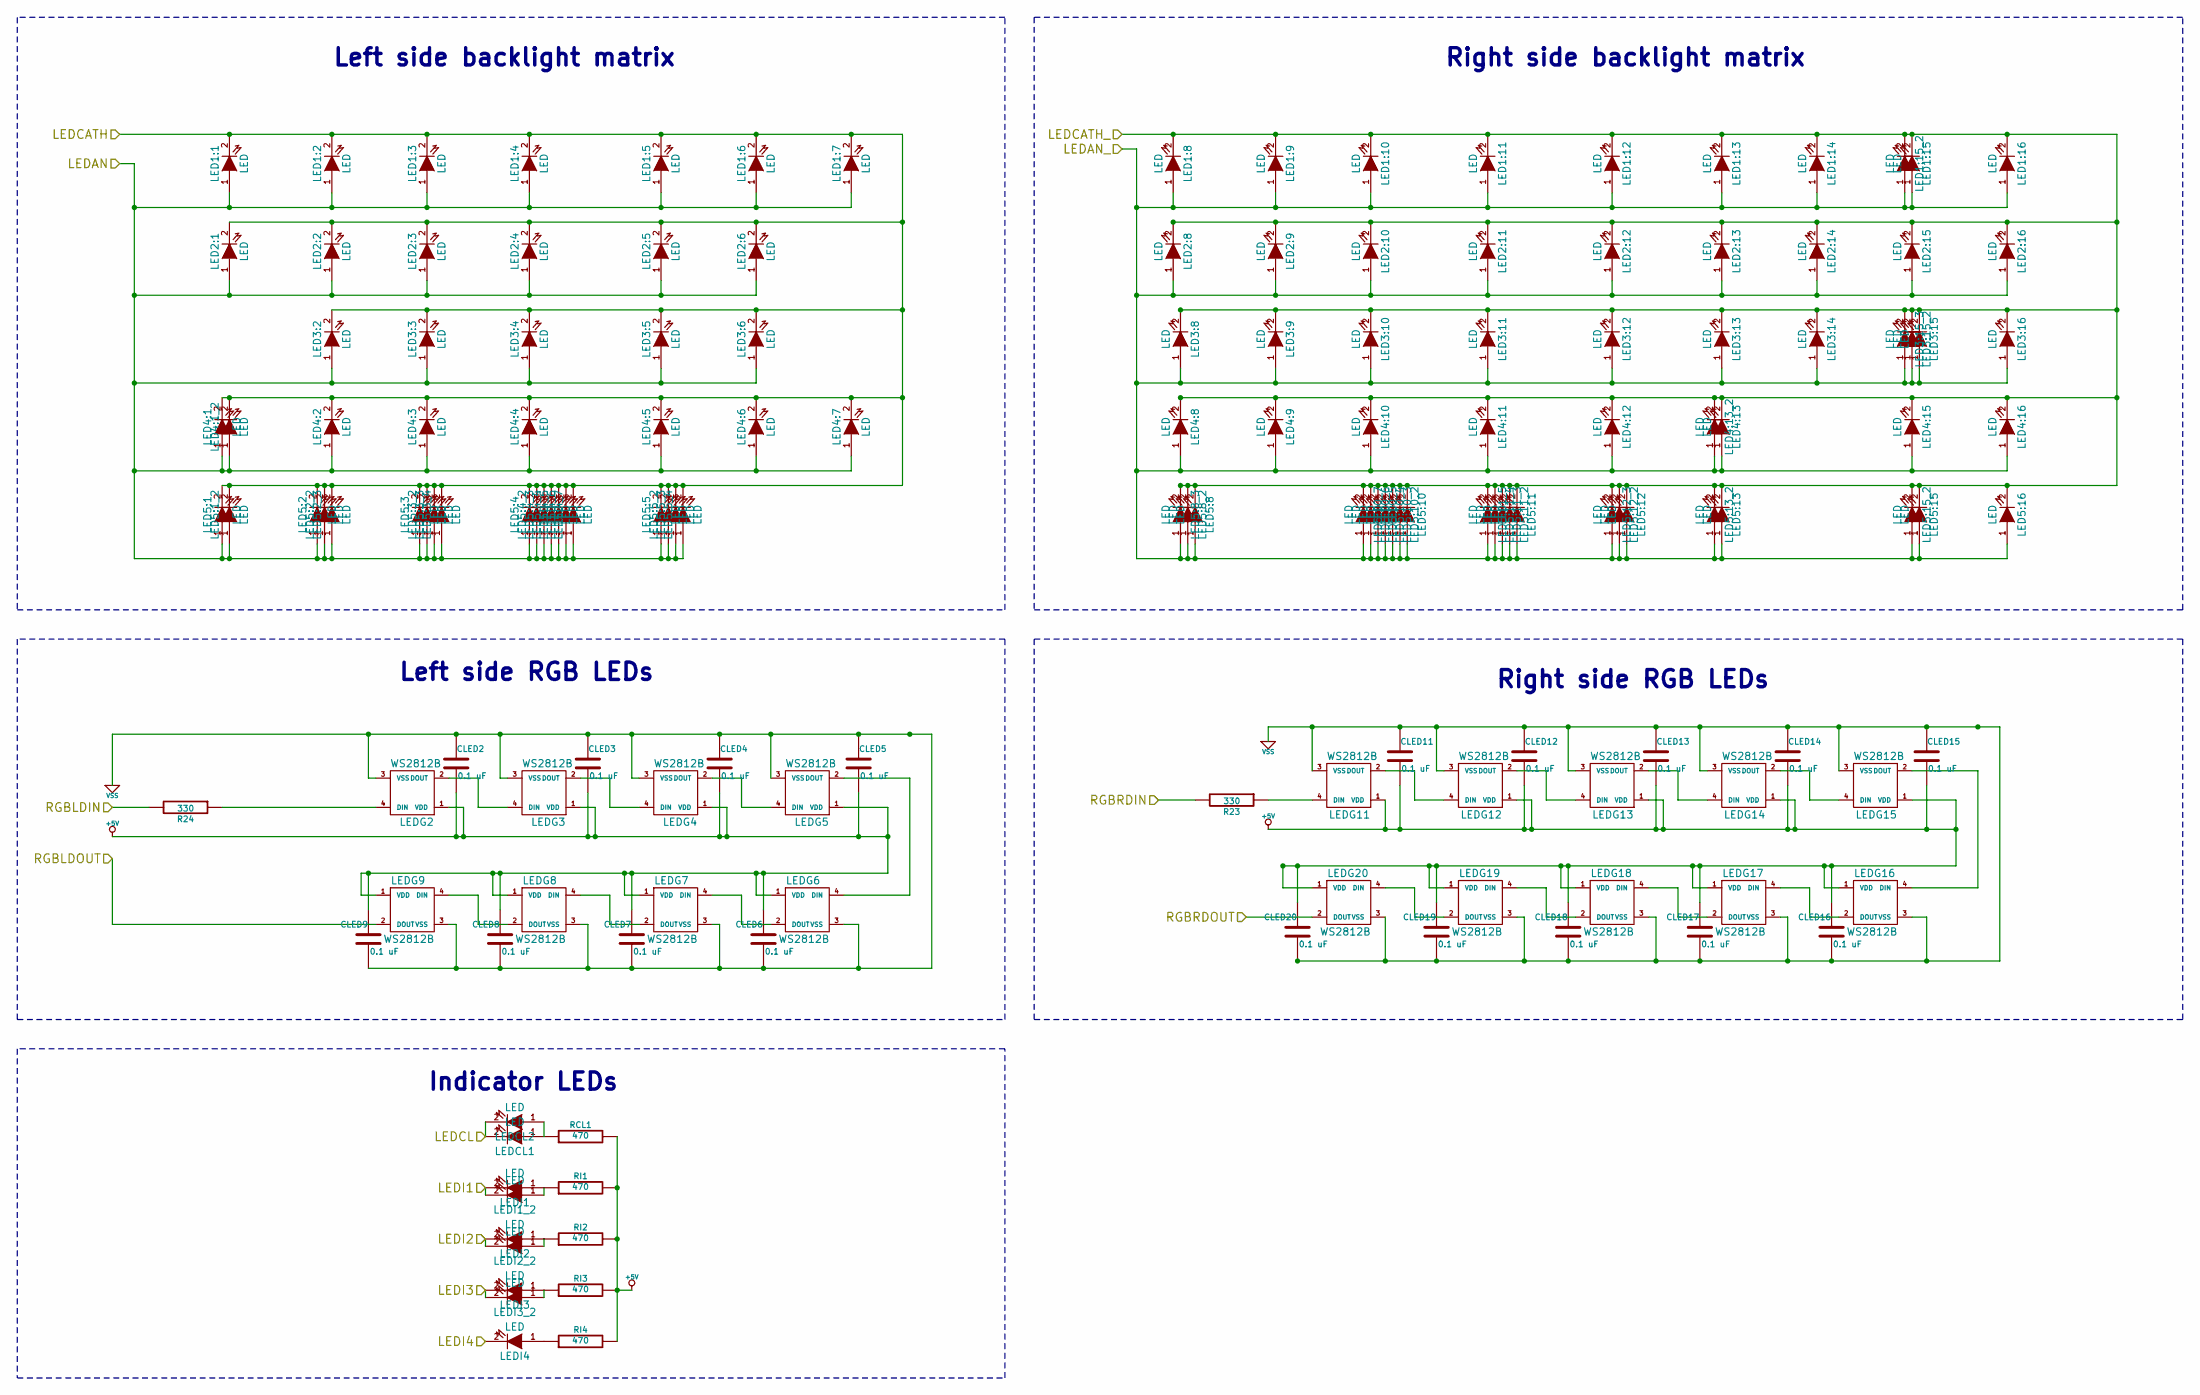
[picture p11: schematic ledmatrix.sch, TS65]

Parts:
CLED2, CLED3, CLED4, CLED5, CLED6, CLED7, CLED8, CLED9, CLED11, CLED12, CLED13, CLED14, CLED15, CLED16, CLED17, CLED18, CLED19, CLED20: 0.1 uF; SMD_0805
LED1:1, LED1:2, LED1:3, LED1:4, LED1:5, LED1:6, LED1:7, LED1:8, LED1:9, LED1:10, LED1:11, LED1:12, LED1:13, LED1:14, LED1:15, LED1:15_2, LED1:16, LED2:1, LED2:2, LED2:3, LED2:4, LED2:5, LED2:6, LED2:8, LED2:9, LED2:10, LED2:11, LED2:12, LED2:13, LED2:14, LED2:15, LED2:16, LED3:2, LED3:3, LED3:4, LED3:5, LED3:6, LED3:8, LED3:9, LED3:10, LED3:11, LED3:12, LED3:13, LED3:14, LED3:15, LED3:15_2, LED3:15_3, LED3:16, LED4:1, LED4:1_2, LED4:2, LED4:3, LED4:4, LED4:5, LED4:6, LED4:7, LED4:8, LED4:9, LED4:10, LED4:11, LED4:12, LED4:13, LED4:13_2, LED4:15, LED4:16, LED5:1, LED5:1_2, LED5:2, LED5:2_2, LED5:2_3, LED5:3, LED5:3_2, LED5:3_3, LED5:3_4, LED5:4, LED5:4_2, LED5:4_3, LED5:4_4, LED5:4_5, LED5:4_6, LED5:4_7, LED5:5, LED5:5_2, LED5:5_3, LED5:5_4, LED5:8, LED5:8_2, LED5:8_3, LED5:10, LED5:10_2, LED5:10_3, LED5:10_4, LED5:10_5, LED5:10_6, LED5:10_7, LED5:11, LED5:11_2, LED5:11_3, LED5:11_4, LED5:11_5, LED5:12, LED5:12_2, LED5:12_3, LED5:13, LED5:13_2, LED5:15, LED5:15_2, LED5:16: LED; INSW_LEDS_REG
LEDCL1, LEDCL2: LED; INSW_LEDS_REG
LEDG2, LEDG3, LEDG4, LEDG5, LEDG6, LEDG7, LEDG8, LEDG9, LEDG11, LEDG12, LEDG13, LEDG14, LEDG15, LEDG16, LEDG17, LEDG18, LEDG19, LEDG20: WS2812B
LEDI1, LEDI1_2, LEDI2, LEDI2_2, LEDI3, LEDI3_2: LED; LED-3MM
LEDI4: LED; LED_0805
R23, R24: 330; SMD_0805
RCL1: 470; SMD_0805
RI1, RI2, RI3, RI4: 470; SMD_0805

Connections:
+5V: CLED2.2, CLED3.2, CLED4.2, CLED5.2, CLED6.1, CLED7.1, CLED8.1, CLED9.1, CLED11.2, CLED12.2, CLED13.2, CLED14.2, CLED15.2, CLED16.1, CLED17.1, CLED18.1, CLED19.1, CLED20.1, LEDG2.1 (VDD), LEDG3.1 (VDD), LEDG4.1 (VDD), LEDG5.1 (VDD), LEDG6.1 (VDD), LEDG7.1 (VDD), LEDG8.1 (VDD), LEDG9.1 (VDD), LEDG11.1 (VDD), LEDG12.1 (VDD), LEDG13.1 (VDD), LEDG14.1 (VDD), LEDG15.1 (VDD), LEDG16.1 (VDD), LEDG17.1 (VDD), LEDG18.1 (VDD), LEDG19.1 (VDD), LEDG20.1 (VDD), RCL1.2, RI1.2, RI2.2, RI3.2, RI4.2; also elsewhere on the board
/ledmatrix/LEDAN: LED1:1.1 (A), LED1:2.1 (A), LED1:3.1 (A), LED1:4.1 (A), LED1:5.1 (A), LED1:6.1 (A), LED1:7.1 (A), LED2:1.1 (A), LED2:2.1 (A), LED2:3.1 (A), LED2:4.1 (A), LED2:5.1 (A), LED2:6.1 (A), LED3:2.1 (A), LED3:3.1 (A), LED3:4.1 (A), LED3:5.1 (A), LED3:6.1 (A), LED4:1.1 (A), LED4:1_2.1 (A), LED4:2.1 (A), LED4:3.1 (A), LED4:4.1 (A), LED4:5.1 (A), LED4:6.1 (A), LED4:7.1 (A), LED5:1.1 (A), LED5:1_2.1 (A), LED5:2.1 (A), LED5:2_2.1 (A), LED5:2_3.1 (A), LED5:3.1 (A), LED5:3_2.1 (A), LED5:3_3.1 (A), LED5:3_4.1 (A), LED5:4.1 (A), LED5:4_2.1 (A), LED5:4_3.1 (A), LED5:4_4.1 (A), LED5:4_5.1 (A), LED5:4_6.1 (A), LED5:4_7.1 (A), LED5:5.1 (A), LED5:5_2.1 (A), LED5:5_3.1 (A), LED5:5_4.1 (A); also elsewhere on the board
/ledmatrix/LEDAN_: LED1:8.1 (A), LED1:9.1 (A), LED1:10.1 (A), LED1:11.1 (A), LED1:12.1 (A), LED1:13.1 (A), LED1:14.1 (A), LED1:15.1 (A), LED1:15_2.1 (A), LED1:16.1 (A), LED2:8.1 (A), LED2:9.1 (A), LED2:10.1 (A), LED2:11.1 (A), LED2:12.1 (A), LED2:13.1 (A), LED2:14.1 (A), LED2:15.1 (A), LED2:16.1 (A), LED3:8.1 (A), LED3:9.1 (A), LED3:10.1 (A), LED3:11.1 (A), LED3:12.1 (A), LED3:13.1 (A), LED3:14.1 (A), LED3:15.1 (A), LED3:15_2.1 (A), LED3:15_3.1 (A), LED3:16.1 (A), LED4:8.1 (A), LED4:9.1 (A), LED4:10.1 (A), LED4:11.1 (A), LED4:12.1 (A), LED4:13.1 (A), LED4:13_2.1 (A), LED4:15.1 (A), LED4:16.1 (A), LED5:8.1 (A), LED5:8_2.1 (A), LED5:8_3.1 (A), LED5:10.1 (A), LED5:10_2.1 (A), LED5:10_3.1 (A), LED5:10_4.1 (A), LED5:10_5.1 (A), LED5:10_6.1 (A), LED5:10_7.1 (A), LED5:11.1 (A), LED5:11_2.1 (A), LED5:11_3.1 (A), LED5:11_4.1 (A), LED5:11_5.1 (A), LED5:12.1 (A), LED5:12_2.1 (A), LED5:12_3.1 (A), LED5:13.1 (A), LED5:13_2.1 (A), LED5:15.1 (A), LED5:15_2.1 (A), LED5:16.1 (A); also elsewhere on the board
/ledmatrix/LEDCATH: LED1:1.2 (K), LED1:2.2 (K), LED1:3.2 (K), LED1:4.2 (K), LED1:5.2 (K), LED1:6.2 (K), LED1:7.2 (K), LED2:1.2 (K), LED2:2.2 (K), LED2:3.2 (K), LED2:4.2 (K), LED2:5.2 (K), LED2:6.2 (K), LED3:2.2 (K), LED3:3.2 (K), LED3:4.2 (K), LED3:5.2 (K), LED3:6.2 (K), LED4:1.2 (K), LED4:1_2.2 (K), LED4:2.2 (K), LED4:3.2 (K), LED4:4.2 (K), LED4:5.2 (K), LED4:6.2 (K), LED4:7.2 (K), LED5:1.2 (K), LED5:1_2.2 (K), LED5:2.2 (K), LED5:2_2.2 (K), LED5:2_3.2 (K), LED5:3.2 (K), LED5:3_2.2 (K), LED5:3_3.2 (K), LED5:3_4.2 (K), LED5:4.2 (K), LED5:4_2.2 (K), LED5:4_3.2 (K), LED5:4_4.2 (K), LED5:4_5.2 (K), LED5:4_6.2 (K), LED5:4_7.2 (K), LED5:5.2 (K), LED5:5_2.2 (K), LED5:5_3.2 (K), LED5:5_4.2 (K); also elsewhere on the board
/ledmatrix/LEDCATH_: LED1:8.2 (K), LED1:9.2 (K), LED1:10.2 (K), LED1:11.2 (K), LED1:12.2 (K), LED1:13.2 (K), LED1:14.2 (K), LED1:15.2 (K), LED1:15_2.2 (K), LED1:16.2 (K), LED2:8.2 (K), LED2:9.2 (K), LED2:10.2 (K), LED2:11.2 (K), LED2:12.2 (K), LED2:13.2 (K), LED2:14.2 (K), LED2:15.2 (K), LED2:16.2 (K), LED3:8.2 (K), LED3:9.2 (K), LED3:10.2 (K), LED3:11.2 (K), LED3:12.2 (K), LED3:13.2 (K), LED3:14.2 (K), LED3:15.2 (K), LED3:15_2.2 (K), LED3:15_3.2 (K), LED3:16.2 (K), LED4:8.2 (K), LED4:9.2 (K), LED4:10.2 (K), LED4:11.2 (K), LED4:12.2 (K), LED4:13.2 (K), LED4:13_2.2 (K), LED4:15.2 (K), LED4:16.2 (K), LED5:8.2 (K), LED5:8_2.2 (K), LED5:8_3.2 (K), LED5:10.2 (K), LED5:10_2.2 (K), LED5:10_3.2 (K), LED5:10_4.2 (K), LED5:10_5.2 (K), LED5:10_6.2 (K), LED5:10_7.2 (K), LED5:11.2 (K), LED5:11_2.2 (K), LED5:11_3.2 (K), LED5:11_4.2 (K), LED5:11_5.2 (K), LED5:12.2 (K), LED5:12_2.2 (K), LED5:12_3.2 (K), LED5:13.2 (K), LED5:13_2.2 (K), LED5:15.2 (K), LED5:15_2.2 (K), LED5:16.2 (K); also elsewhere on the board
/ledmatrix/LEDCL: LEDCL1.2 (K), LEDCL2.2 (K); also elsewhere on the board
/ledmatrix/LEDI1: LEDI1.2 (K), LEDI1_2.2 (K); also elsewhere on the board
/ledmatrix/LEDI2: LEDI2.2 (K), LEDI2_2.2 (K); also elsewhere on the board
/ledmatrix/LEDI3: LEDI3.2 (K), LEDI3_2.2 (K); also elsewhere on the board
/ledmatrix/LEDI4: LEDI4.2 (K); also elsewhere on the board
/ledmatrix/RGBLDIN: R24.2; also elsewhere on the board
/ledmatrix/RGBLDOUT: LEDG9.2 (DOUT); also elsewhere on the board
/ledmatrix/RGBRDIN: R23.2; also elsewhere on the board
/ledmatrix/RGBRDOUT: LEDG20.2 (DOUT); also elsewhere on the board
unnamed: LEDCL1.1 (A), LEDCL2.1 (A), RCL1.1
unnamed: LEDG2.2 (DOUT), LEDG3.4 (DIN)
unnamed: LEDG2.4 (DIN), R24.1
unnamed: LEDG3.2 (DOUT), LEDG4.4 (DIN)
unnamed: LEDG4.2 (DOUT), LEDG5.4 (DIN)
unnamed: LEDG5.2 (DOUT), LEDG6.4 (DIN)
unnamed: LEDG6.2 (DOUT), LEDG7.4 (DIN)
unnamed: LEDG7.2 (DOUT), LEDG8.4 (DIN)
unnamed: LEDG8.2 (DOUT), LEDG9.4 (DIN)
unnamed: LEDG11.2 (DOUT), LEDG12.4 (DIN)
unnamed: LEDG11.4 (DIN), R23.1
unnamed: LEDG12.2 (DOUT), LEDG13.4 (DIN)
unnamed: LEDG13.2 (DOUT), LEDG14.4 (DIN)
unnamed: LEDG14.2 (DOUT), LEDG15.4 (DIN)
unnamed: LEDG15.2 (DOUT), LEDG16.4 (DIN)
unnamed: LEDG16.2 (DOUT), LEDG17.4 (DIN)
unnamed: LEDG17.2 (DOUT), LEDG18.4 (DIN)
unnamed: LEDG18.2 (DOUT), LEDG19.4 (DIN)
unnamed: LEDG19.2 (DOUT), LEDG20.4 (DIN)
unnamed: LEDI1.1 (A), LEDI1_2.1 (A), RI1.1
unnamed: LEDI2.1 (A), LEDI2_2.1 (A), RI2.1
unnamed: LEDI3.1 (A), LEDI3_2.1 (A), RI3.1
unnamed: LEDI4.1 (A), RI4.1
VSS: CLED2.1, CLED3.1, CLED4.1, CLED5.1, CLED6.2, CLED7.2, CLED8.2, CLED9.2, CLED11.1, CLED12.1, CLED13.1, CLED14.1, CLED15.1, CLED16.2, CLED17.2, CLED18.2, CLED19.2, CLED20.2, LEDG2.3 (VSS), LEDG3.3 (VSS), LEDG4.3 (VSS), LEDG5.3 (VSS), LEDG6.3 (VSS), LEDG7.3 (VSS), LEDG8.3 (VSS), LEDG9.3 (VSS), LEDG11.3 (VSS), LEDG12.3 (VSS), LEDG13.3 (VSS), LEDG14.3 (VSS), LEDG15.3 (VSS), LEDG16.3 (VSS), LEDG17.3 (VSS), LEDG18.3 (VSS), LEDG19.3 (VSS), LEDG20.3 (VSS); also elsewhere on the board

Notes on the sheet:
Left side backlight matrix
Right side backlight matrix
Right side RGB LEDs
Left side RGB LEDs
Indicator LEDs

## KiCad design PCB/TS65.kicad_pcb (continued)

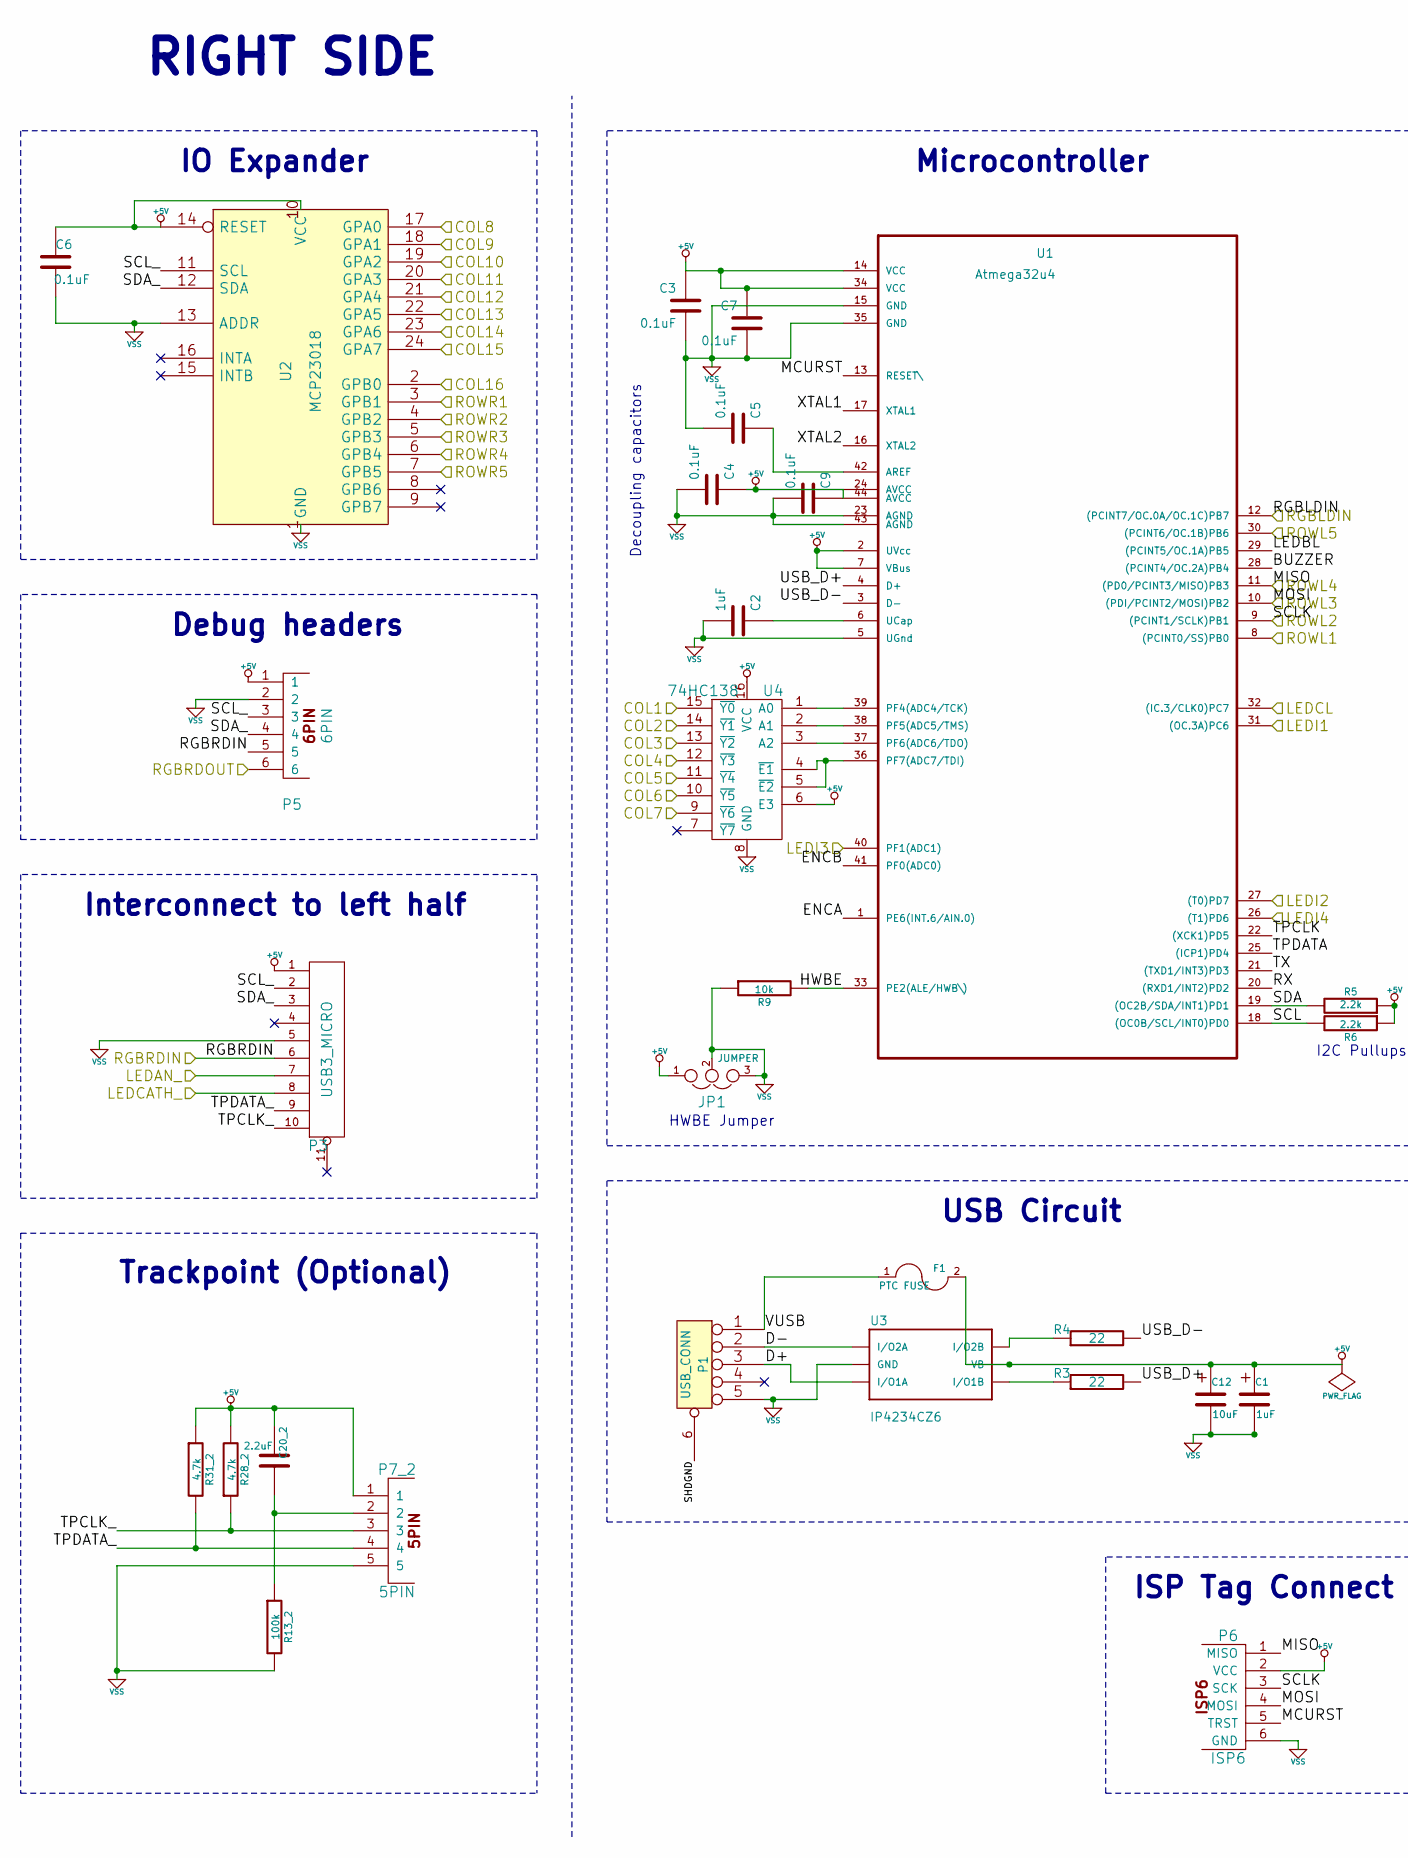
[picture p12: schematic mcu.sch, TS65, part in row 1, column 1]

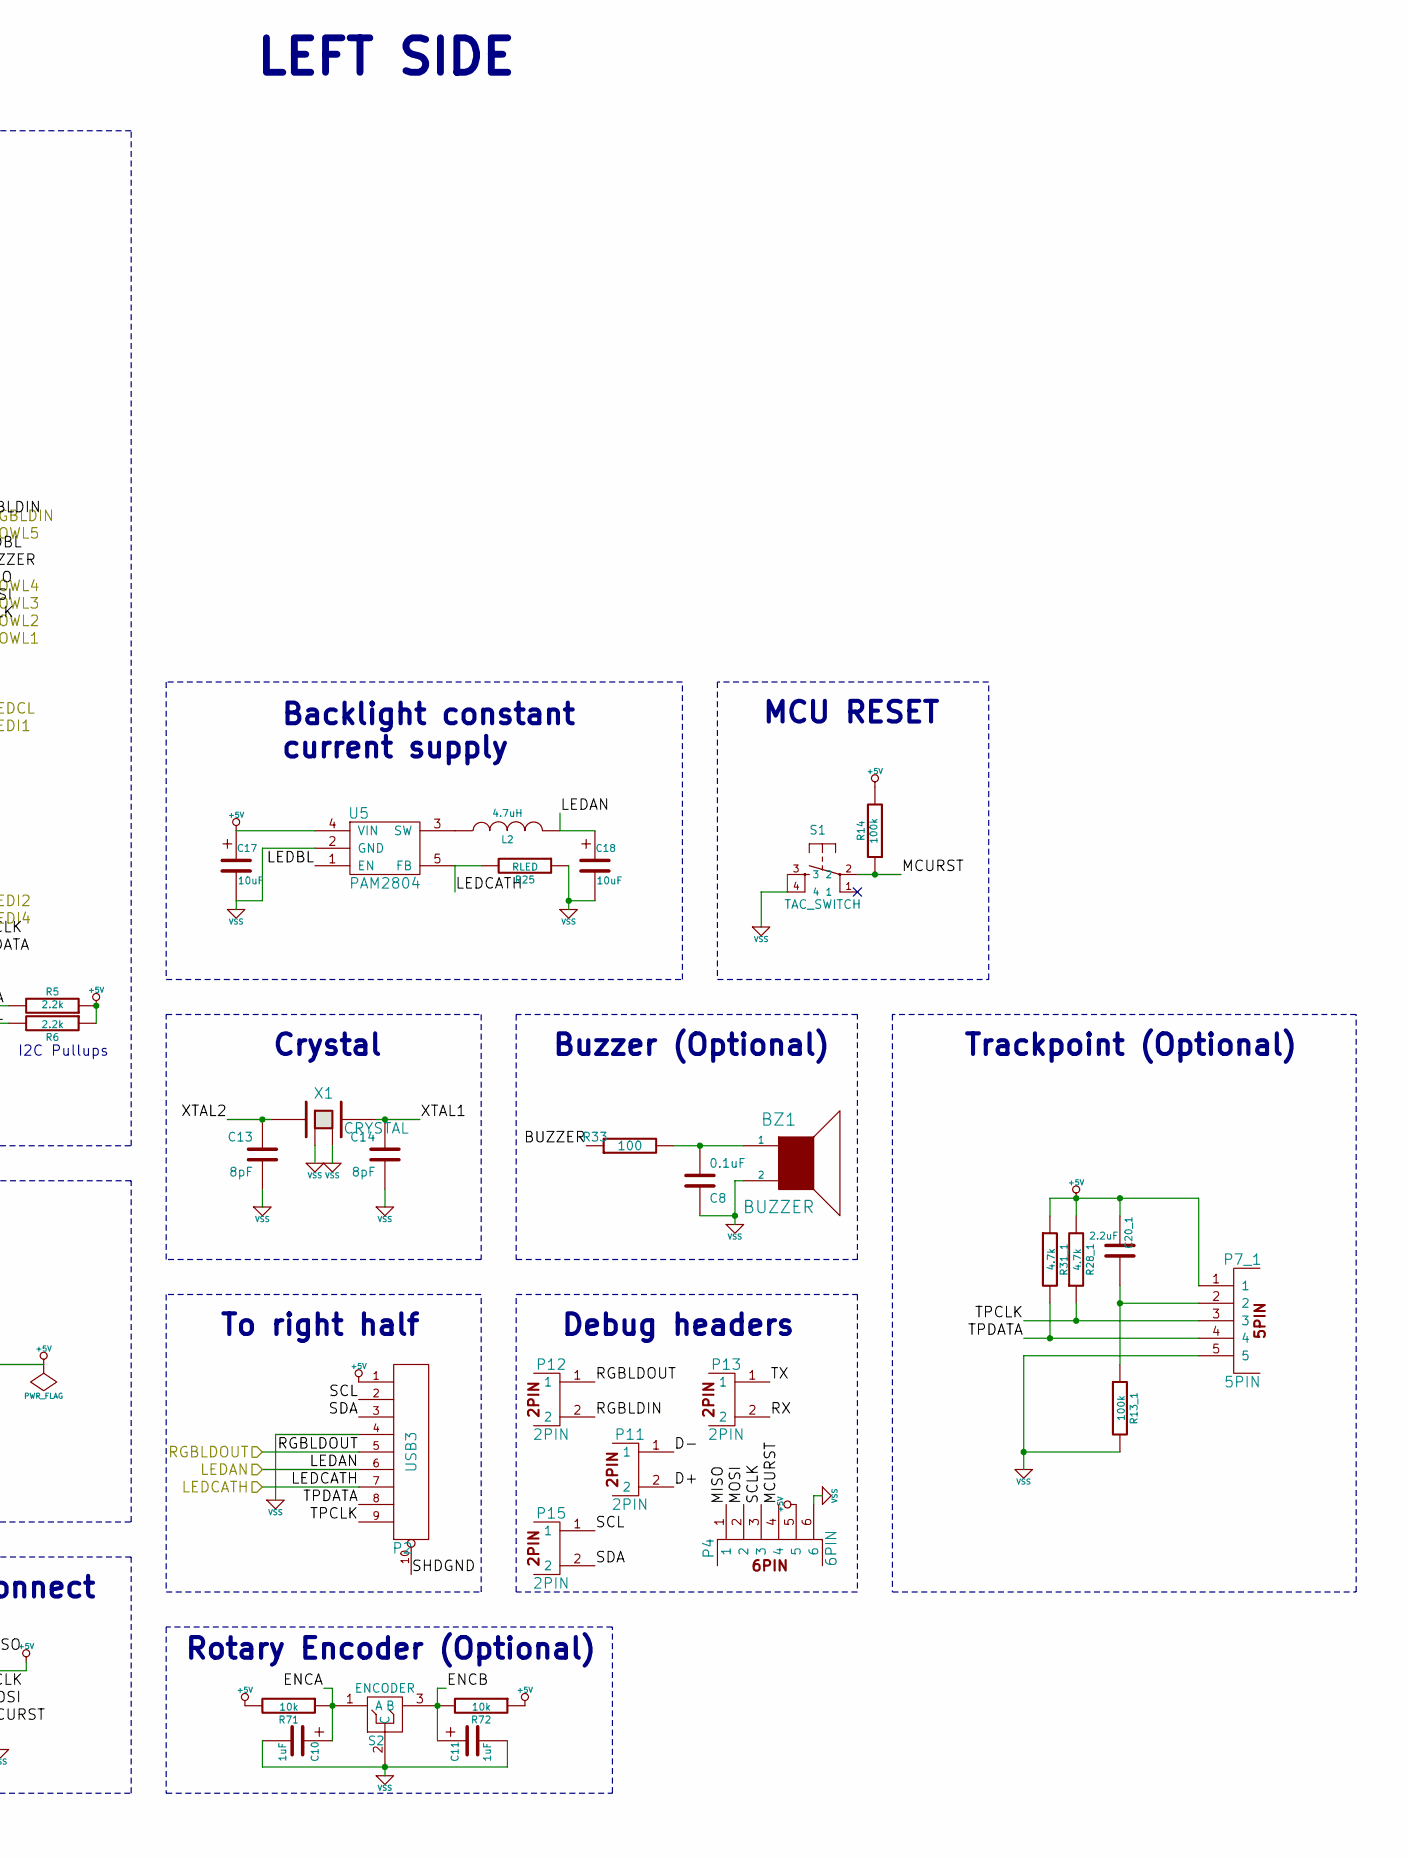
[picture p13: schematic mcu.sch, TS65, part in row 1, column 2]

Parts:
BZ1: BUZZER; BUZZER_SMT
C1, C2, C10, C11: 1uF; SMD_0805
C3, C4, C5, C6, C7, C8, C9: 0.1uF; SMD_0805
C12, C17, C18: 10uF; SMD_0805
C13, C14: 8pF; SMD_0805
C20_1, C20_2: 2.2uF; SMD_0805
F1: PTC FUSE; Fuse_SMD1206
JP1: JUMPER; JUMPER_SMD_3
L2: 4.7uH; Inductor_Bourn_4mmx4mm
P1: USB_CONN; USB_Micro-B
P2: USB3; USB3_AFEMALE_MOD
P3: USB3_MICRO; USB3_MICROB
P4, P5: 6PIN; Pin_Header_1x06
P6: ISP6; TC2030_BIG
P7_1, P7_2: 5PIN; Pin_Header_1x05
P11, P12, P13, P15: 2PIN; Pin_Header_1x02
R3, R4: 22; SMD_0805
R5, R6: 2.2k; SMD_0805
R9, R71, R72: 10k; SMD_0805
R13_1, R13_2, R14: 100k; SMD_0805
R25: RLED; SMD_0805
R28_1, R28_2, R31_1, R31_2: 4.7k; SMD_0805
R33: 100; SMD_0805
S1: TAC_SWITCH; TACT_5.2x5.2
S2: ENCODER; ENCODER_12MM
U1: Atmega32u4; TQFP44
U2: MCP23018; SSOP-24
U3: IP4234CZ6; SOT457
U4: 74HC138; SO-16-N
U5: PAM2804; SOT-23-5
X1: CRYSTAL; NX3225SA

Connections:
+5V: C1.1, C3.1, C4.1, C6.1, C7.1, C9.1, C12.1, C17.1, C20_1.2, C20_2.2, F1.2, JP1.1, P2.1, P3.1, P4.5, P5.1, P6.2 (VCC), P7_1.1, P7_2.1, R5.1, R6.1, R14.2, R28_1.2, R28_2.2, R31_1.1, R31_2.1, R71.2, R72.1, U1.2 (UVcc), U1.7 (VBus), U1.14 (VCC), U1.24 (AVCC), U1.34 (VCC), U1.44 (AVCC), U2.10 (VCC), U2.14 (RESET), U3.5 (VB), U4.6 (E3), U4.16 (VCC), U5.4 (VIN); also elsewhere on the board
/Col1: U4.15 (~Y0); also elsewhere on the board
/Col2: U4.14 (~Y1); also elsewhere on the board
/Col3: U4.13 (~Y2); also elsewhere on the board
/Col4: U4.12 (~Y3); also elsewhere on the board
/Col5: U4.11 (~Y4); also elsewhere on the board
/Col6: U4.10 (~Y5); also elsewhere on the board
/Col7: U4.9 (~Y6); also elsewhere on the board
/Col8: U2.17 (GPA0); also elsewhere on the board
/Col9: U2.18 (GPA1); also elsewhere on the board
/Col10: U2.19 (GPA2); also elsewhere on the board
/Col11: U2.20 (GPA3); also elsewhere on the board
/Col12: U2.21 (GPA4); also elsewhere on the board
/Col13: U2.22 (GPA5); also elsewhere on the board
/Col14: U2.23 (GPA6); also elsewhere on the board
/Col15: U2.24 (GPA7); also elsewhere on the board
/Col16: U2.2 (GPB0); also elsewhere on the board
/RowL1: U1.8 ((PCINT0/SS)PB0); also elsewhere on the board
/RowL2: P4.3, P6.3 (SCK), U1.9 ((PCINT1/SCLK)PB1); also elsewhere on the board
/RowL3: P4.2, P6.4 (MOSI), U1.10 ((PDI/PCINT2/MOSI)PB2); also elsewhere on the board
/RowL4: P4.1, P6.1 (MISO), U1.11 ((PD0/PCINT3/MISO)PB3); also elsewhere on the board
/RowL5: U1.30 ((PCINT6/OC.1B)PB6); also elsewhere on the board
/RowR1: U2.3 (GPB1); also elsewhere on the board
/RowR2: U2.4 (GPB2); also elsewhere on the board
/RowR3: U2.5 (GPB3); also elsewhere on the board
/RowR4: U2.6 (GPB4); also elsewhere on the board
/RowR5: U2.7 (GPB5); also elsewhere on the board
/ledmatrix/LEDAN: C18.1, L2.2, P2.6; also elsewhere on the board
/ledmatrix/LEDAN_: P3.7; also elsewhere on the board
/ledmatrix/LEDCATH: P2.7, R25.2, U5.5 (FB); also elsewhere on the board
/ledmatrix/LEDCATH_: P3.8; also elsewhere on the board
/ledmatrix/LEDCL: U1.32 ((IC.3/CLK0)PC7); also elsewhere on the board
/ledmatrix/LEDI1: U1.31 ((OC.3A)PC6); also elsewhere on the board
/ledmatrix/LEDI2: U1.27 ((T0)PD7); also elsewhere on the board
/ledmatrix/LEDI3: U1.40 (PF1(ADC1)); also elsewhere on the board
/ledmatrix/LEDI4: U1.26 ((T1)PD6); also elsewhere on the board
/ledmatrix/RGBLDIN: P12.2, U1.12 ((PCINT7/OC.0A/OC.1C)PB7); also elsewhere on the board
/ledmatrix/RGBLDOUT: P2.5, P12.1; also elsewhere on the board
/ledmatrix/RGBRDIN: P3.6, P5.5; also elsewhere on the board
/ledmatrix/RGBRDOUT: P5.6; also elsewhere on the board
/mcu/BUZZER: R33.1, U1.28 ((PCINT4/OC.2A)PB4)
/mcu/D+: P1.3, P11.2, U3.4 (I/O1A)
/mcu/D-: P1.2, P11.1, U3.3 (I/O2A)
/mcu/ENCA: C10.1, R71.1, S2.1 (A), U1.1 (PE6(INT.6/AIN.0))
/mcu/ENCB: C11.1, R72.2, S2.3 (B), U1.41 (PF0(ADC0))
/mcu/HWBE: R9.2, U1.33 (PE2(ALE/HWB\))
/mcu/LEDBL: U1.29 ((PCINT5/OC.1A)PB5), U5.1 (EN)
/mcu/MCURST: P4.4, P6.5 (TRST), R14.1, S1.2, U1.13 (RESET\)
/mcu/RX: P13.2, U1.20 ((RXD1/INT2)PD2)
/mcu/SCL: P2.2, P15.1, R6.2, U1.18 ((OC0B/SCL/INT0)PD0)
/mcu/SCL_: P3.2, P5.3, U2.11 (SCL)
/mcu/SDA: P2.3, P15.2, R5.2, U1.19 ((OC2B/SDA/INT1)PD1)
/mcu/SDA_: P3.3, P5.4, U2.12 (SDA)
/mcu/SHDGND: P1.6, P2.10
/mcu/TPCLK: P2.9, P7_1.3, R28_1.1, U1.22 ((XCK1)PD5)
/mcu/TPCLK_: P3.10, P7_2.3, R28_2.1
/mcu/TPDATA: P2.8, P7_1.4, R31_1.2, U1.25 ((ICP1)PD4)
/mcu/TPDATA_: P3.9, P7_2.4, R31_2.2
/mcu/TX: P13.1, U1.21 ((TXD1/INT3)PD3)
/mcu/USB_D+: R3.2, U1.4 (D+)
/mcu/USB_D-: R4.2, U1.3 (D-)
/mcu/VUSB: F1.1, P1.1
/mcu/XTAL1: C14.1, U1.17 (XTAL1), X1.3
/mcu/XTAL2: C13.1, U1.16 (XTAL2), X1.1
unnamed: BZ1.1, C8.2, R33.2
unnamed: C2.1, U1.6 (UCap)
unnamed: C5.1, U1.42 (AREF)
unnamed: C20_1.1, P7_1.2, R13_1.1
unnamed: C20_2.1, P7_2.2, R13_2.1
unnamed: L2.1, U5.3 (SW)
unnamed: R3.1, U3.6 (I/O1B)
unnamed: R4.1, U3.1 (I/O2B)
unnamed: U1.36 (PF7(ADC7/TDI)), U4.4 (~E1), U4.5 (~E2)
unnamed: U1.37 (PF6(ADC6/TDO)), U4.3 (A2)
unnamed: U1.38 (PF5(ADC5/TMS)), U4.2 (A1)
unnamed: U1.39 (PF4(ADC4/TCK)), U4.1 (A0)
VSS: BZ1.2, C1.2, C2.2, C3.2, C4.2, C5.2, C6.2, C7.2, C8.1, C9.2, C10.2, C11.2, C12.2, C13.2, C14.2, C17.2, C18.2, JP1.2, JP1.3, P1.5, P2.4, P3.5, P4.6, P5.2, P6.6 (GND), P7_1.5, P7_2.5, R9.1, R13_1.2, R13_2.2, R25.1, S1.3, S1.4, S2.2 (C), U1.5 (UGnd), U1.15 (GND), U1.23 (AGND), U1.35 (GND), U1.43 (AGND), U2.1 (GND), U2.13 (ADDR), U3.2 (GND), U4.8 (GND), U5.2 (GND), X1.2, X1.4; also elsewhere on the board

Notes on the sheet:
IO Expander
Interconnect to left half
Debug headers
Trackpoint (Optional)
RIGHT SIDE
USB Circuit
To right half
Backlight constant current supply
ISP Tag Connect
Crystal
MCU RESET
Buzzer (Optional)
Microcontroller
HWBE Jumper
I2C Pullups
Decoupling capacitors
LEFT SIDE
Rotary Encoder (Optional)

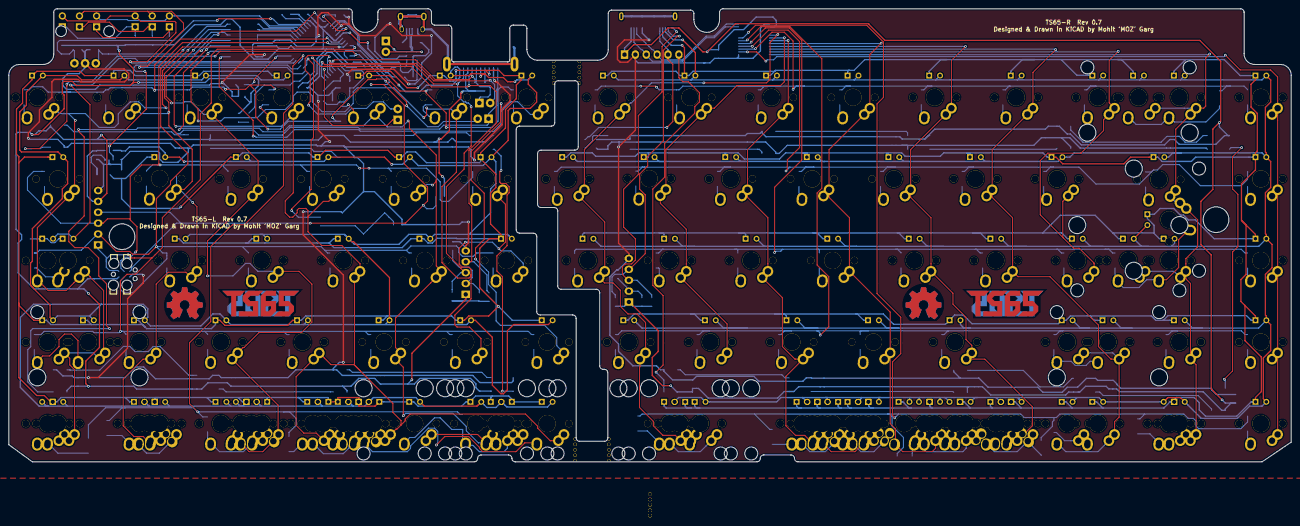
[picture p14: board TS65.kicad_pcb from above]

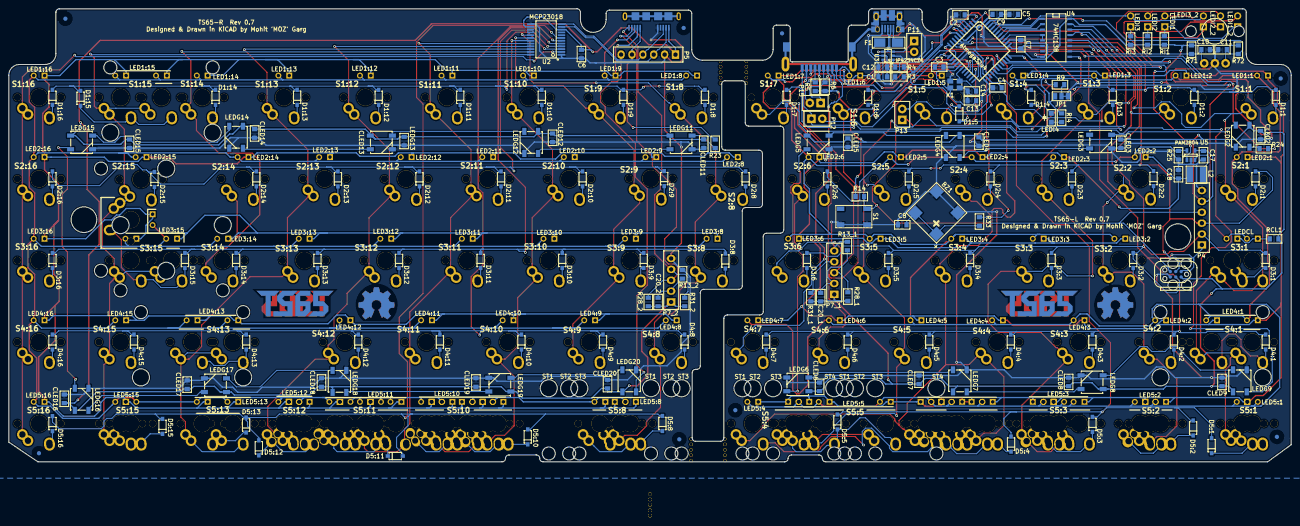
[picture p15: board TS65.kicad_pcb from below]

Board: 2 copper layers, 299.5 x 105.8 mm, 437 parts (193 on the bottom side), 173 nets.

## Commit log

2016-05-02 Rev 0.6
    [TS65-B.Mask.gbs, TS65-B.SilkS.gbo, TS65-Back.gbl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]
2016-05-10 Upload BOM
2016-05-20 Rev 0.7
    [TS65-B.Mask.gbs, TS65-B.Paste.gbp, TS65-B.SilkS.gbo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]
2017-04-27 Update BOM
    Added designators for WS2812B
2017-05-19 Rev 0.7.1
    - Corrected pin mappings for right half connector
    [TS65-B.Mask.gbs, TS65-B.Paste.gbp, TS65-B.SilkS.gbo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]
2017-07-20 Add 3d printed case for the TS65 keyboard
    Reference https://geekhack.org/index.php?topic=79161.msg2462175#msg2462175
    [Bottom-Right.stl, Plate-Left.stl, Plate-Right.stl]
2017-07-20 Remove unneeded hole from bottom left
    Remove unneeded hole from bottom left
2017-07-22 Increase gap between keys and case
    [Plate-Left.stl, Plate-Right.stl]
2018-07-23 Adding re-modeled Fusion360 case model.
